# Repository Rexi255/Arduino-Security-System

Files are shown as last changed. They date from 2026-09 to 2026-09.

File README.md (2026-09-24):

<p align="center">
  Projekt GAS: mini security system with keypad, RFID reader and motion sensor
</p>

<p align="center">
  <a href="https://bbz-aifs51.github.io/LF7-Projekt_GAS/"><b>▶ Open the 3D model in your browser</b></a>
  &nbsp;·&nbsp; <a href="MDs/anleitung.md">User manual (German)</a>
  &nbsp;·&nbsp; <a href="Schaltplan/SCHALTPLAN.png">Schematic</a>
  &nbsp;·&nbsp; <a href="Code/alarm_system/alarm_system.ino">Firmware</a>
</p>

A small alarm system on an Arduino Uno R3, built as a school project for
learning field 7 (LF07). You arm and disarm it with a PIN on a 4x4 keypad or
with an RFID card. While it is armed, the motion sensor triggers a 30-second
siren. The OLED only shows icons: a heart when the system is disarmed, a skull
when it is armed, and a flashing skull during an alarm. You add cards right on
the device, no PC needed.

<p align="center">
  State machine: disarmed, exit delay, armed, alarm and admin menu
</p>

## Features

- **Two ways to arm and disarm:** PIN + `#` on the keypad, or a stored RFID card. Both do exactly the same thing.
- **Exit delay:** After arming you have 10 s to leave the room. The buzzer beeps once per second in the meantime.
- **Alarm:** It starts on motion (only while ARMED) or after **3 wrong tries** (wrong PIN or unknown card). The siren runs for 30 s or until the correct PIN or a known card is used.
- **Feedback:** A bright double tone means OK, a rough buzz means an error. The PIN only shows up as `*`, and a wrong entry briefly shows a ✖.
- **Admin menu on the device:** `A` + admin PIN + `#` opens it. There you add cards (just hold them to the reader), or browse and delete the stored ones. Cards live in the internal EEPROM and survive a new upload.
- **RFID reset:** `B` restarts the RC522 in case a clone module hangs.

## Quick controls

| Key | Action |
|---|---|
| `0`–`9` | enter the PIN (shown as `*`) |
| `#` | confirm the entry |
| `*` | clear the entry · in the admin menu: back / exit |
| `A` | while DISARMED: enter the admin PIN → admin menu |
| `B` | while DISARMED: re-initialise the RFID reader |
| Hold a card to the reader | same as the correct PIN (if the card is stored) |

The full end-user manual (in German) is in [MDs/anleitung.md](MDs/anleitung.md),
and as a PDF in [Anleitung/](Anleitung/Mini%20Security%20System%20Manual.pdf).

## Hardware

| Part | Uno connection | Note |
|---|---|---|
| Arduino Uno R3 | – | ATmega328P, 2 KB SRAM |
| 4x4 keypad | rows R1–R4 → D9–D6, columns C1–C4 → D5–D2 | the sketch scans the matrix itself |
| 1.3" OLED 128x64 | SDA → A4, SCL → A5 | **SH1106** controller, I²C address `0x3C` |
| RFID-RC522 | SS → A0, RST → A1, MOSI → D11, MISO → D12, SCK → D13 | **VCC to 3.3 V**, 5 V destroys the module |
| Motion sensor (PIR) | OUT → A2 | active HIGH |
| Passive buzzer | signal → D10 | driven directly from the pin, no transistor |
| 9 V battery | barrel jack | power supply |

All other VCC pins go to 5 V, all GND pins to a common ground. This uses up
every pin on the Uno; only D0/D1 (serial) are left free. The full parts list
is in [Teile.xlsx](Teile.xlsx).

<p align="center">
  Wiring of all parts to the Arduino Uno
</p>

The original Cirkit Designer schematic is in
[Schaltplan/](Schaltplan/SCHALTPLAN.png) (PNG and SVG).

## Getting started

1. Install the **Arduino IDE** and get these libraries from the Library Manager:
   - **Adafruit SH110X** (also install its dependencies *Adafruit GFX* and *Adafruit BusIO*)
   - **MFRC522** (GithubCommunity)
   - **Keypad** (Mark Stanley / Alexander Brevig), only needed for `hardware_test`
   - `Wire`, `SPI` and `EEPROM` already come with the IDE.
2. Set the PIN and admin PIN at the top of [alarm_system.ino](Code/alarm_system/alarm_system.ino) (`PIN_CODE`, `ADMIN_PIN`).
3. Select the **Arduino Uno** board and the right port, then upload.
4. Set the serial monitor to **9600 baud**. On start-up it shows the RC522 version (`0x91`/`0x92` = OK), the number of stored cards and the free SRAM.
5. On the very first start the EEPROM is empty, so the sketch writes the factory list `DEFAULT_UIDS` into it. After that you manage cards only through the admin menu.

If something doesn't work, the test sketches check each part on its own:

| Sketch | Purpose |
|---|---|
| [Code/alarm_system/](Code/alarm_system/alarm_system.ino) | **Main firmware**: state machine, PIN, RFID, admin menu, sounds |
| [Code/hardware_test/](Code/hardware_test/hardware_test.ino) | bring-up test: OLED, keypad, buzzer, motion sensor |
| [Code/display_test/](Code/display_test/display_test.ino) | OLED only (icons + free SRAM) |
| [Code/rfid_test/](Code/rfid_test/rfid_test.ino) | RC522 only (version, UID of every card) |

## 3D model in the browser

**[▶ bbz-aifs51.github.io/LF7-Projekt_GAS](https://bbz-aifs51.github.io/LF7-Projekt_GAS/)**

An interactive 3D model of the build (three.js), laid out after the schematic.
It runs the firmware logic from `alarm_system.ino`, so the states, timings,
sounds and OLED graphics are the same:

- Press keys on the 3D keypad or in the side panel. Your keyboard works too (Enter = `#`, Esc = `*`).
- Click the cards or the key fob: they float over to the RC522 and the SPI lines light up.
- Click the motion sensor to trigger the alarm while ARMED.
- A signal pulse travels along each wire. A key press lights up exactly its row and column wire, and the L LED on D13 flickers during SPI traffic.
- The buzzer plays through WebAudio, and there is a serial monitor and an EEPROM card list.

The model uses demo PINs (`1234` and admin `0000`), not the real ones from the
sketch. To use it offline, just open
[docs/viewer/index.html](docs/viewer/index.html) in your browser.

## Pitfalls we solved

- **The OLED is an SH1106, not an SSD1306.** With the SSD1306 library it stays blank or only shows stripes. The right class is `Adafruit_SH1106G`.
- **SRAM is tight.** The OLED buffer alone takes 1024 of the 2048 bytes. With the Keypad library only ~205 bytes were left, which caused resets and wrong key presses. So the sketch scans the matrix itself, and all strings are kept in flash with `F()`.
- **`SPI.begin()` drives D10 HIGH**, because D10 is the AVR's SS pin. That is exactly where the buzzer sits, so the sketch sets the buzzer pin LOW only *after* `SPI.begin()`.
- **The motion sensor moved to A2**, because D11 is the fixed SPI MOSI pin. A2 works just like any digital pin with `digitalRead()`.
- **Polling the RC522 blocks for ~25 ms** when no card is present. So the sketch only polls the reader every 200 ms, otherwise the keypad gets sluggish and the siren stutters.

## Project structure

| Folder/file | Contents |
|---|---|
| [Code/](Code/) | Arduino sketches, one subfolder per sketch |
| [docs/](docs/) | animated README graphics (SVG) and the 3D viewer (`docs/viewer/`) |
| [MDs/](MDs/) | docs (German): [hardware spec](MDs/aufbau.md), [user manual](MDs/anleitung.md), [development log](MDs/entwicklungsverlauf.md) |
| [Anleitung/](Anleitung/) | user manual as a PDF |
| [Schaltplan/](Schaltplan/) | schematic (PNG/SVG) |
| [Teile.xlsx](Teile.xlsx) | parts list |
| [CLAUDE.md](CLAUDE.md) | project context and hardware facts for development with Claude Code |

The firmware was written together with Claude Code. Every prompt and answer is
logged (in German) in [MDs/entwicklungsverlauf.md](MDs/entwicklungsverlauf.md).

## License

[MIT](LICENSE). The 3D viewer uses [three.js](https://threejs.org/) (MIT,
bundled as `docs/viewer/three.min.js`).

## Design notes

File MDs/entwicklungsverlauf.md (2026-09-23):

# Entwicklungsverlauf — Projekt GAS

Dokumentation der Firmware-Entwicklung mit Claude Code (Claude Opus 5).
Chronologisches Protokoll: Prompts (Jan Mummert) und Antworten (Claude).

- Projekt: LF07 — Mini-Sicherheitssystem / Access Lock (Arduino Uno R3)
- Daten der Sitzungen: 08.09.2026, 22.09.2026, 23.09.2026 (inkl. Gehäuse)
- Grundlagen im Kontext: [../CLAUDE.md](../CLAUDE.md), [aufbau.md](aufbau.md)

---

## 1. Prompt — Auftrag: komplette Firmware

> Use @CLAUDE.md und @MDs/aufbau.md.
>
> Programmiere den kompletten Code für unser Projekt.
>
> Was wir wollen: Ein mini Sicherheitssystem/Doorlock/Access Lock.
> Der Buzzer soll einen Alarmton abspielen, wenn der Motion sensor ausgelöst
> ist. Man soll die Alarmanlage mit einem Pin (später auch mit rfid, aber das
> ist nur eine Idee für ein feature wenn alles läuft) entschärfen können und
> auch wieder mit dem Pin scharf schalten können. Das Display soll im scharfen
> zustand einen Totenkopf anzeigen, wenn man Pin eingibt sollen anstelle des
> Pins nur Sternchen "*" angezeigt werden, die Eingabe des Pins soll man mit
> "#" bestätigen können. Bei richtigem Pin soll ein heller angenehmer
> Bestätigungston kommen, Bei Falsch eingabe ein Rauer längerer Ton (3sek).
> Bei 3 facher fehleingabe soll der Alarm der Anlage ertönen.
> Im Entsperrten zustand soll das Display ein Herz anzeigen.
>
> Im Unscharfen zustand soll der Motion Sensor natürlich keinen Alarm auslösen,
> nur wenn die Anlage scharf ist.
> Der Alarm soll extrem laut und schrill sein, er soll 30 sekunden dauern.

### Antwort

Fertig: [../Code/alarm_system/alarm_system.ino](../Code/alarm_system/alarm_system.ino)
— die komplette Firmware, Pins genau wie in aufbau.md/CLAUDE.md
(SDA=A4, SCL=A5, SH1106 @0x3C).

**Zustände**

- `UNSCHARF` — Herz auf dem Display, Bewegungssensor wird ignoriert.
- `SCHARF IN xs` — Ausgangsverzögerung (10 s, Piep pro Sekunde), damit du nach
  dem Scharfschalten den Raum verlassen kannst, ohne dich selbst auszulösen.
  Das hattest du nicht verlangt, ohne das löst die Anlage aber sofort beim
  eigenen Zurücktreten aus — Wert steht als `EXIT_DELAY_MS` oben, auf 0 setzen
  wenn du es nicht willst.
- `SCHARF` — Totenkopf, Bewegung (steigende Flanke auf D11) löst Alarm aus.
- `ALARM` — blinkendes „ALARM!!", Totenkopf, Restsekunden; Sirene 30 s, danach
  automatisch wieder scharf.

**Bedienung am Keypad**

- `0-9` PIN eingeben, auf dem Display nur `*` (Größe 2, mittig)
- `#` bestätigen → richtiger PIN schaltet scharf/unscharf und beendet den
  laufenden Alarm sofort
- `*` Eingabe löschen; halb getippte PIN verfällt nach 10 s von selbst
- PIN steht oben als `const char PIN_CODE[] = "1234";`

**Töne** (nicht-blockierend, Keypad bleibt währenddessen bedienbar)

- Richtig: zwei helle kurze Noten (G6 → C7)
- Falsch: rauer tiefer Brummton, 3 s (schnelles Wechseln 95/135 Hz)
- 3× falsch: voller Alarm — das gilt in jedem Zustand, also auch im unscharfen
  (Sabotage). Wenn du das nur im scharfen Zustand willst, sag Bescheid.
- Alarm: Sirenen-Sweep 2500↔3700 Hz, bewusst im lautesten Bereich des Piezos,
  30 s

**Nicht verifiziert:** Ich konnte den Sketch hier nicht kompilieren —
arduino-cli ist auf dem Rechner nicht vorhanden. Bitte einmal in der Arduino
IDE bauen und hochladen; die Bibliotheken sind dieselben wie beim
`hardware_test`.

---

## 2. Prompt — Display zeigt Pixelmüll

> Das Display bugt ein wenig, es zeigt weder das herz, noch einen totenkopf
> oder ähnliches an. Auch der Code etc. wird nicht richtig angezeigt. man kann
> die sekundne timer erahnen, aber das wars. Das display hat diese specs:
>
> - Module dimensions: 36 mm x 34 mm x 3 mm
> - Dot Matrix: 128 x 64
> - Pixel size: 0.21 mm × 0.21 mm
> - Pixel pitch: 0.23 mm × 0.23 mm
> - Display Mode: Passive Matrix
> - Duty: 1/64 Duty
> - Display Color: Blue
> - Interface: I2C
> - Power consumption: Less then 11mA
> - Size: 1.3 inch

### Antwort

Das klingt nach einem Anzeige-/Speicherproblem, nicht nach falscher Geometrie —
1,3" 128x64 I2C ist praktisch immer der SH1106, und der `hardware_test` lief ja.
Ich mache zwei Dinge: einen isolierten Display-Test zum Eingrenzen und die
Hauptfirmware deutlich RAM-sparsamer.

Der wahrscheinlichste Verdacht: Der Uno hat 2 KB SRAM, der Framebuffer belegt
davon allein 1 KB. `snprintf("%lu")` und die Text-Literale im RAM treiben den
Stack so weit hoch, dass er in den Framebuffer läuft — das ergibt genau so ein
Bild, in dem man Reste (die Sekundenzahlen) noch erahnen kann.

Zwei Sachen, bitte in dieser Reihenfolge testen:

**1. [../Code/display_test/display_test.ino](../Code/display_test/display_test.ino)
hochladen** (nur das Display, sonst nichts). Er zeigt im 2-Sekunden-Takt:
Rahmen+Text → Herz → Totenkopf → `****`, und schreibt vor jedem Bild den freien
SRAM in den Seriellen Monitor.

- Sehen die vier Bilder korrekt aus → das Display kann alles, das Problem ist
  der Speicher im Hauptsketch (siehe Punkt 2).
- Sind sie auch hier kaputt → es liegt am Display selbst; dann sag mir bitte,
  *wie* kaputt (verschoben, gestreift, Rauschen) und was der Rahmen macht. Dann
  ist der Controller vermutlich doch kein SH1106, und ich baue auf SSD1306 bzw.
  auf einen Spaltenversatz um.

**2. [../Code/alarm_system/alarm_system.ino](../Code/alarm_system/alarm_system.ino)
ist überarbeitet.** Was ich geändert habe und warum:

Der Uno hat 2048 Byte SRAM, davon frisst der OLED-Framebuffer allein 1024. Dazu
Keypad-Library, Wire- und Serial-Puffer — es bleiben nur ein paar hundert Byte
Stack. `snprintf("%lu")` braucht davon über 100 Byte auf einen Schlag, und die
Text-Literale `"UNSCHARF"` usw. lagen zusätzlich im RAM. Wenn der Stack in den
Framebuffer läuft, sieht man genau das, was du beschreibst: Pixelmüll, in dem
man Reste (deine Sekundenzahlen) noch erahnen kann.

Deshalb jetzt:

- kein `snprintf` mehr — der Countdown wird direkt mit `display.print()`
  ausgegeben
- alle Display-Texte über `F(...)` im Flash statt im RAM
- keine temporären `char`-Puffer mehr (die Sternchen werden in einer Schleife
  gedruckt)
- `setup()` gibt `free SRAM:` über Serial aus — der Wert sollte deutlich über
  250 liegen

Der Funktionsumfang ist unverändert. Die Icons habe ich zusätzlich leicht
anders positioniert, damit sich Totenkopf und die Sternchen-Zeile nicht mehr
überlappen.

Melde mir die vier Testbilder und den SRAM-Wert, dann weiß ich, in welche
Richtung es geht. Kompilieren kann ich hier weiterhin nicht — auf dem Rechner
ist keine arduino-cli installiert.

---

## 3. Prompt — Dokumentation

> Packe alle Prompts von mir und deine antworten in einer .md datei. wir
> brauchen das als dokumentation

### Antwort

Dieses Dokument. Es wird bei weiteren Änderungen fortgeschrieben.

---

## 4. Prompt — Resets beim Scharfschalten, Text soll weg

> Funktioniert soweit.
>
> 1. Sehr oft, nachdem es einmal armed und disarmed wurde kann man es nicht
>    erneut armen. Es zeigt im serial pin wrong an obwohl dieser richtig
>    eingegeben wurde:
>
>    ```
>    free SRAM: 205
>    [PIN] wrong 1
>    [PIN] correct
>    [STATE] arming - exit de=== Alarm system ready (disarmed) ===
>    PIN + '#' arms / disarms, '*' clears the entry.
>    free SRAM: 205
>    [PIN] wrong 1
>    ```
>
> 2. Entferne den Text bei den Symbolen, es soll nur Totenkopf oder Herz ohne
>    Text angezeigt werden. Der Sekundentimer ist etwas zu groß, die hälfte der
>    Zahl verschwindet weil es über den display rand hinaus geht.

### Antwort

**Zu 1 — der Arduino startet neu.** Im Log bricht die Zeile
`[STATE] arming - exit de` mitten im Wort ab und danach kommt wieder der
Startbanner `=== Alarm system ready ===`. Das ist ein Reset, kein Logikfehler.
Ursache ist der freie SRAM: **205 Byte**. Davon muss der komplette Stack leben,
inklusive der Interrupts, die `tone()` erzeugt (bei 3700 Hz sind das 7400
Interrupts pro Sekunde). Wenn so ein Interrupt zuschlägt, während der
Display-Code tief im Stack steht, läuft der Stack in den Framebuffer und in die
globalen Variablen — mal gibt es einen Reset, mal wird nur `entry[]` verfälscht,
und dann meldet der Sketch „PIN wrong" obwohl richtig getippt wurde. Das erklärt
auch, warum es erst *nach* dem ersten Scharfschalten auftritt: vorher hat noch
kein Ton gespielt.

Der größte Speicherfresser nach dem Framebuffer war die **Keypad-Library**: sie
hält 10 `Key`-Objekte, eine Bitmap und die Keymap im RAM, zusammen rund 120 Byte.
Die habe ich rausgeworfen und den 4x4-Scan selbst geschrieben — für eine Matrix
sind das ungefähr 30 Zeilen:

- Zeilen auf `INPUT_PULLUP`, Spalten hochohmig (`INPUT`)
- pro Scan eine Spalte auf `OUTPUT`/LOW ziehen und die vier Zeilen lesen
- Keymap liegt jetzt im Flash (`PROGMEM` + `pgm_read_byte`)
- eigenes Entprellen (20 ms), eine Taste wird genau einmal beim Drücken gemeldet

Damit sollten rund **320–330 Byte** frei sein. Der Wert steht wie vorher beim
Start im Seriellen Monitor — bitte einmal nachsehen und mir sagen, was dasteht.
Zusätzlich gibt der Sketch jetzt jede erkannte Taste (`[KEY] 4`) und die
komplette Eingabe vor der Prüfung (`[PIN] entered: 1234`) aus. Falls doch noch
etwas verschluckt wird, sieht man es damit sofort.

Die Keypad-Library wird für diesen Sketch nicht mehr gebraucht; der
`hardware_test` benutzt sie weiterhin, also bitte installiert lassen.

**Zu 2 — Anzeige.** Aller Statustext ist raus, es gibt nur noch die Icons:

- UNSCHARF: Herz, mittig
- SCHARF: Totenkopf, mittig
- Ausgangsverzögerung: Totenkopf + Countdown darunter
- ALARM: Totenkopf, der im 250-ms-Takt das ganze Display invertiert, darunter
  die Restsekunden (auch das „ALARM!!" ist weg — sagt Bescheid, wenn ihr das
  Wort zurückhaben wollt)

Der abgeschnittene Countdown war ein vertikales Problem, kein horizontales: die
Zahl stand in Größe 2 auf y = 52, das sind 16 Pixel Höhe bis y = 68 — das
Display hört bei 63 auf, also fehlte die untere Hälfte. Jetzt sitzt sie auf
y = 46 bzw. y = 47 und passt.

Während der PIN-Eingabe zeigt das Display nur noch die Sternchen, groß und
mittig. Grund: Totenkopf und Sternchen brauchen zusammen mehr als 64 Pixel Höhe,
sie hätten sich sonst überlappt.

---

## 5. Prompt — Kollisionserkennung und Rechtevergabe bei RFID

> Erkläre uns was unsere Lehrerin mit Kollisionserkennung und Rechtevergabe im
> bezug auf RFID meint

### Antwort

Zwei verschiedene Ebenen, die beim RFID-Teil oft durcheinander geworfen werden:

**Kollisionserkennung — Protokoll-Ebene (ISO 14443A)**

Liegen mehrere Karten gleichzeitig im Feld des RC522, würden bei einer
einfachen Anfrage alle gleichzeitig antworten — das ist eine *Kollision*. Der
ISO-14443A-Standard löst das über ein Anti-Kollisions-Verfahren: Der Reader
fragt die UID Bit für Bit in Kaskaden ab, bis genau eine Karte eindeutig
identifiziert ist. Bei uns läuft das komplett innerhalb der MFRC522-Library ab,
über die Aufrufe

```cpp
mfrc522.PICC_IsNewCardPresent()
mfrc522.PICC_ReadCardSerial()
```

in [readRfidUid()](../Code/alarm_system/alarm_system.ino#L326). Der Aufruf
[mfrc522.PICC_HaltA()](../Code/alarm_system/alarm_system.ino#L339) danach
schickt die gelesene Karte in den HALT-Zustand, damit sie nicht bei jedem
Poll-Zyklus erneut "kollidiert" bzw. neu gelesen wird, solange sie liegen
bleibt.

**Rechtevergabe — Anwendungsebene (Access Control)**

Unsere jetzige Logik ist rein binär: Eine UID steht in
[ALLOWED_UIDS](../Code/alarm_system/alarm_system.ino#L77) oder nicht, geprüft
in [isAllowedUid()](../Code/alarm_system/alarm_system.ino#L350) — jede erlaubte
Karte darf alles, was das System kann (scharf/unscharf schalten). Mit
"Rechtevergabe" ist vermutlich eine feinere Unterscheidung gemeint, z. B.:

- unterschiedliche Rollen pro Karte (manche dürfen nur entschärfen, andere
  auch neue Karten anlernen)
- Karten zur Laufzeit hinzufügen/entziehen können, statt sie fest im Code
  (`PROGMEM`) zu hinterlegen
- Protokollierung, wer wann welche Karte benutzt hat, statt nur ja/nein

Für den Umfang dieses Schulprojekts bleibt es bei der einfachen
Allow-List-Prüfung — das oben ist als konzeptionelle Erklärung für die
Dokumentation/Präsentation gedacht, nicht als Implementierungsauftrag.

---

## 6. Prompt — Rechtevergabe umsetzen: UIDs außerhalb des Codes verwalten

> Thema Rechtevergabe. Man soll die uids außerhalb des Codes verändern, bzw.
> sperren oder hinzufügen können. Wie könnte man das lösen. Plane erst

### Antwort

Aufbauend auf Eintrag 5 (dort nur konzeptionell besprochen, bewusst nicht
umgesetzt) jetzt tatsächlich implementiert, nach Rückfrage zur Bedienung:

- Admin-Interface komplett über Keypad + OLED (keine Serial-Kommandos, kein
  PC nötig)
- Löschen entfernt eine UID sofort, keine separate Sperrliste

**Speicherung:** UIDs liegen jetzt im internen EEPROM des Uno statt fest im
Code (`DEFAULT_UIDS` bleibt nur als Werksvorgabe fürs allererste Booten).
Kein Zusatzmodul (z. B. SD-Karte) nötig und laut CLAUDE.md auch gar nicht
möglich — kein Pin mehr frei. EEPROM übersteht ein Neu-Hochladen des Sketches.

**Bedienung:** Taste `A` im UNSCHARF-Zustand + eine eigene `ADMIN_PIN` + `#`
öffnet einen neuen Zustand `STATE_ADMIN` mit kleinem Text-Menü auf dem OLED
(bisher zeigte das Display nur Icons — hier bewusste Ausnahme, siehe
[Code/alarm_system/alarm_system.ino](../Code/alarm_system/alarm_system.ino#L885)):

- `1` Karte anlernen — auflegen genügt, kein manuelles Abtippen der Hex-UID
  mehr (das war vorher nötig, siehe `rfid_test.ino`)
- `2` Liste durchblättern (`#`), Karte löschen (`D`)
- `*` Menü verlassen; nach `ADMIN_IDLE_TIMEOUT_MS` (20 s) auch automatisch

Eine falsche Admin-PIN läuft über denselben `accessDenied()`-Pfad wie eine
falsche normale PIN — zählt also zu den 3 Fehlversuchen und löst genauso
Alarm aus (Bruteforce-Schutz für beide PINs einheitlich).

`MAX_STORED_UIDS` bewusst klein (8) gewählt wegen des knappen SRAMs (siehe
Memory Note in CLAUDE.md) — mehr Platz wäre im EEPROM (1024 Byte) locker da,
das RAM ist der eigentliche Engpass.

Vor der Änderung wurde eine Kopie der alten Version unter
`Code/alarm_system/alarm_system.ino.bak` gesichert.

**Offener Punkt:** Wie in Eintrag 4 — kein `arduino-cli` auf diesem Rechner,
der Sketch wurde nicht kompiliert. Vor dem Hochladen in der Arduino IDE
verifizieren und danach die Punkte aus dem Plan durchgehen (u. a.: passt
`free SRAM` noch, wandert die bestehende `DEFAULT_UIDS`-Karte korrekt ins
EEPROM, funktioniert Anlernen/Löschen, löst 3x falsche Admin-PIN den Alarm
aus, übersteht eine neue Karte ein erneutes Hochladen).

---

## 7. Prompt — RFID-Reset (22.09.2026)

> Unsere Lehrerin hat bei einer anderen Gruppe angemerkt, dass sie keinen
> RFID-Reset haben, da sich das RFID-Modul wohl öfters mal aufhängen kann.
> Wie könnten wir sowas bei uns einbauen, bzw. ist das überhaupt nötig? Falls
> ja könnte man da ja auch z. B. den Buchstaben B beim Tastenfeld setzen.

### Antwort

Ja, sinnvoll: RC522-Klone können SPI-seitig hängen bleiben (`VersionReg`
antwortet dann wieder mit `0x00`/`0xFF` statt `0x91`/`0x92`), erkennbar an
Karten, die plötzlich nicht mehr gelesen werden — sonst hilft nur ein
kompletter Neustart des Uno. `RST_PIN` (A1) ist bei uns ohnehin schon
verdrahtet, ein Reset zur Laufzeit ist also reine Software.

Rückfrage, ob nur manuell per Taste, zusätzlich automatisch im Hintergrund,
oder gar nicht — Antwort: nur manuell. Umgesetzt in
[../Code/alarm_system/alarm_system.ino](../Code/alarm_system/alarm_system.ino):

- Neue Funktion `resetRfid()` (`PCD_Reset()` + `PCD_Init()`, danach
  `VersionReg` neu geprüft und `rfidOk` aktualisiert; OK-/Fehlerton als
  Feedback)
- Taste `B` im Zustand UNSCHARF ruft `resetRfid()` auf — bisher unbelegt,
  analog zur `A`-Abfrage fürs Admin-Menü (nur bei `entryLen == 0`)
- Kopf-Kommentar im Sketch und [../CLAUDE.md](../CLAUDE.md) (Abschnitt
  „Sketches") entsprechend ergänzt

**Offener Punkt:** wie in den vorherigen Einträgen nicht kompiliert (kein
`arduino-cli` auf dem Rechner) — vor dem nächsten Hochladen in der Arduino
IDE prüfen, außerdem am echten Aufbau testen, ob `B` den Reader nach einem
gezielten Verbindungsabbruch (z. B. RST kurz trennen) tatsächlich wiederbelebt.

---

## 8. Prompt — 3D-Animationen und neue README (23.09.2026)

> Schaue dir dieses Github Repo von einem freund an:
> https://github.com/BBZ-AIFS51/LF7-MiniCasino
>
> Ich möchte das in dem Github repo von diesem Projekt auch so coole 3d
> animationen wie bei denen sind. Verwende dafür unsere dokumentation. Dabei
> kannst du Auch gleich die README unseres Projekts einmal komplett überarbeiten

### Antwort

Das MiniCasino-Repo nutzt zwei Dinge: animierte SVG-Grafiken direkt in der
README (CSS-Animationen, laufen auch auf GitHub) und einen three.js-3D-Viewer,
der über GitHub Pages läuft. Beides gibt es jetzt auch bei uns, aufgebaut aus
CLAUDE.md, aufbau.md, anleitung.md, dem Schaltplan und der Firmware:

- [../docs/banner.svg](../docs/banner.svg): isometrisches Gerät, das in 10 s
  einmal UNSCHARF → PIN → SCHARF → ALARM durchläuft. Herz und Totenkopf mit
  denselben Koordinaten wie `drawHeart()`/`drawSkull()`, die Alarm-Anzeige
  invertiert wie im Sketch, dazu eine schwebende RFID-Karte.
- [../docs/how-it-works.svg](../docs/how-it-works.svg): Zustandsautomat mit
  laufenden Pfeilen, dem jeweils aktiven Zustand und Fortschrittsbalken für
  10 s / 30 s.
- [../docs/wiring.svg](../docs/wiring.svg): Verdrahtung am Uno, Signalpulse
  zeigen die Richtung, Hinweis auf 3,3 V beim RC522.
- [../docs/viewer/index.html](../docs/viewer/index.html): 3D-Modell des
  Steckbrett-Aufbaus nach dem Schaltplan. Die Firmware-Logik ist 1:1 nach
  JavaScript übertragen (Zustände, Zeiten, Töne über WebAudio, OLED als
  128x64-Framebuffer mit denselben GFX-Aufrufen, Admin-Menü, EEPROM im
  localStorage). Tasten, Karten und PIR sind anklickbar, Signalpulse laufen
  über die Kabel. Im Modell gelten Demo-PINs (`1234`/`0000`), nicht die echten.
- [../.github/workflows/pages.yml](../.github/workflows/pages.yml): veröffentlicht
  den Viewer auf GitHub Pages.
- [../README.md](../README.md) komplett neu geschrieben.

Getestet: SVGs und Viewer im Edge (headless) gerendert, die Viewer-Logik mit
einem Skript durchgespielt (PIN, Ausgangszeit, Bewegung → Alarm,
3 Fehlversuche, Admin-PIN, Karte anlernen/löschen, 7-Byte-UID abgelehnt,
Eingabe-Timeout). Alle Prüfungen sind bestanden.

**Offener Punkt:** GitHub Pages muss einmalig unter *Settings → Pages →
Source: GitHub Actions* aktiviert werden. Der Fehlerton dauert laut Sketch
`ERROR_TONE_MS = 2000` (2 s), Kommentare und CLAUDE.md sagen noch 3 s.

---

## 9. Prompt — README, Grafiken und Viewer auf Englisch (23.09.2026)

> Ändere die Readme auf englisch
>
> Ja stelle auch den viewer auf englisch um und pushe alles dann

### Antwort

[../README.md](../README.md) ins Englische übersetzt (Inhalt unverändert,
deutsche Doku-Links mit „(German)“ markiert). Alle Texte in den drei SVGs unter
[../docs/](../docs/) und die komplette Oberfläche des 3D-Viewers (Seitenleiste,
Tooltips, Beschriftungen, Kartenaufdrucke) sind jetzt englisch. Die OLED- und
Serial-Texte waren schon englisch, weil sie aus dem Sketch stammen. Grafik und
Viewer danach erneut gerendert und geprüft.

---

## 10. Prompt — Gehäuse für den 3D-Druck (23.09.2026)

> Plane und entwerfe ein Gehäuse. Das Gehäuse soll 3D gedruckt werden. Ich habe
> 0 Erfahrung was sowas angeht.
>
> Wichtig ist, dass der Bewegungssensor auf der anderen seite sein muss, also
> quasi ist alles vorne an einer tür/Türrahmen und auch der anderen seite ist
> der bewegungssensor, sodass er halt erst was erkennt wenn man den raum
> betritt und nicht auslöst wenn man nur an den türrahmen rantritt um es zu
> entsperren.
>
> Plane erst das Gehäuse, dann entwerfe es

### Antwort

Zwei Gehäuse statt einem: **Bedienteil** außen neben der Tür (Uno, Keypad,
OLED, RC522, Buzzer, 90 × 176 × 45 mm) und **Sensorteil** innen im Raum
(HC-SR501, 52 × 44 × 35 mm), verbunden über ein 3-adriges Kabel. Der PIR sieht
nur in direkter Sichtlinie, die Wand verdeckt also die Person am Bedienteil.

- [gehaeuse.md](gehaeuse.md): Planung (Konzept, Aufteilung, Montageort) und
  Einsteiger-Anleitung (Nachmessen, Slicen, Einkaufsliste, Zusammenbau,
  Anpassen in OpenSCAD).
- [../Gehaeuse/gehaeuse.scad](../Gehaeuse/gehaeuse.scad): parametrisches
  OpenSCAD-Modell, alle Maße oben als Variablen.
- [../Gehaeuse/stl/](../Gehaeuse/stl/): vier fertige Druckteile, bereits in
  Druckrichtung, ohne Stützstrukturen druckbar.

Mit OpenSCAD 2021.01 gerendert: alle vier STLs sind geschlossen („Simple:
yes“). Die Frontansicht wurde auf nicht gespiegelte Gravuren geprüft.
**Offener Punkt:** Die Modulmaße stammen aus Datenblättern und sind nicht am
echten Aufbau gemessen. Außerdem ist noch nichts gedruckt.

---

## Anhang — Stand der Dateien

| Datei | Zweck |
|---|---|
| [../Code/hardware_test/hardware_test.ino](../Code/hardware_test/hardware_test.ino) | Bring-up-Test aller Bauteile (vor dieser Sitzung entstanden) |
| [../Code/alarm_system/alarm_system.ino](../Code/alarm_system/alarm_system.ino) | Hauptfirmware: Zustandsautomat, PIN, Icons, Töne |
| [../Code/display_test/display_test.ino](../Code/display_test/display_test.ino) | Isolierter OLED-Test + SRAM-Anzeige zur Fehlersuche |
| [../CLAUDE.md](../CLAUDE.md) | Projektvorgaben, Pinbelegung, Hardware-Fakten, SRAM-Hinweis |

**Offener Punkt:** Die Reset-Diagnose (zu wenig freier SRAM) gilt erst als
bestätigt, wenn der neue `free SRAM:`-Wert im Seriellen Monitor deutlich über
300 liegt und die Resets ausbleiben. Kein Sketch
dieser Sitzung wurde kompiliert, da auf dem Rechner keine arduino-cli vorhanden
ist.

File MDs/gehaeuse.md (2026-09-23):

# Gehäuse — Planung und Entwurf

3D-druckbares Gehäuse für das Mini-Sicherheitssystem. Geschrieben für
Einsteiger: Es wird nichts an Vorwissen über 3D-Druck vorausgesetzt.

- Modell (zum Anpassen): [../Gehaeuse/gehaeuse.scad](../Gehaeuse/gehaeuse.scad)
- Fertige Druckdateien: [../Gehaeuse/stl/](../Gehaeuse/stl/)
- Bilder: [../Gehaeuse/bilder/](../Gehaeuse/bilder/)

---

## Teil 1 — Planung

### Anforderungen

1. Keypad, Display, RFID-Leser und Buzzer sitzen **außen** an der Tür bzw.
   neben dem Türrahmen — dort wird ent- und verriegelt.
2. Der Bewegungssensor sitzt **auf der anderen Seite, im Raum**. Er soll erst
   auslösen, wenn jemand den Raum betritt, nicht schon, wenn man zum
   Entsperren vor der Tür steht.
3. Druckbar ohne Erfahrung: keine Stützstrukturen, passt auf kleine Drucker,
   Befestigung mit einfachen Schrauben und Heißkleber.
4. Keine Änderung an Firmware oder Verdrahtung nötig.

### Konzept: zwei Gehäuse, ein Kabel

Montage von oben

- **Bedienteil** (außen): Keypad, OLED, RC522, Buzzer und der Arduino Uno.
- **Sensorteil** (innen): nur der HC-SR501.
- Verbunden über ein **3-adriges Kabel** (5V, GND, OUT → A2). Der Bewegungs-
  sensor braucht nur diese drei Leitungen, ein langes Kabel ist für das
  digitale Signal kein Problem.

**Warum das funktioniert:** Ein PIR-Sensor „sieht“ Wärmestrahlung nur in
direkter Sichtlinie. Wände, Türen und sogar normales Glas blockieren sie.
Der Sensor zeigt in den Raum, die Wand steht zwischen ihm und der Person am
Bedienteil — die kann er also gar nicht erfassen. Erst wer die Tür öffnet
und eintritt, läuft in den Erfassungsbereich.

### Bedienteil (außen)

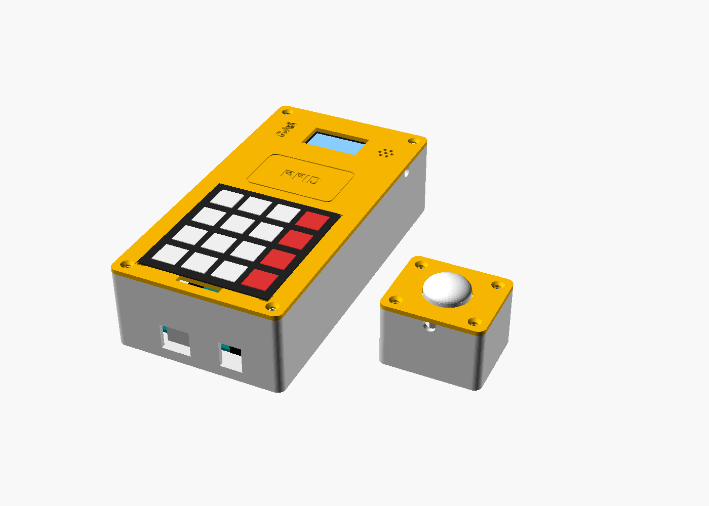
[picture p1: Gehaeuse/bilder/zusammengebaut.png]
Bedienteil zusammengebaut


Größe: **90 × 176 × 45 mm** (B × H × T). Zwei Druckteile: Rückteil (Wanne) und
Frontplatte.

| Bereich | Bauteil | Befestigung |
|---|---|---|
| oben | OLED hinter einem Fenster (32 × 18 mm) | seitliche Führungen, nach oben/unten schiebbar bis das Bild mittig sitzt, dann Heißkleber |
| oben rechts | Buzzer hinter 7 Schalllöchern | Ring als Halter + Heißkleber |
| Mitte | RC522 hinter der Frontplatte, Feld „RFID“ eingraviert | vier Eckführungen + Heißkleber. Die Karte liest durch 2,4 mm Kunststoff problemlos |
| unten | Folien-Keypad **außen aufgeklebt** (Klebefolie auf der Rückseite) | Eckmarken zeigen die Position, das Flachkabel geht durch einen Schlitz direkt darunter |
| hinten | Arduino Uno auf 4 Abstandshaltern, USB-/Strombuchse zeigt nach unten | 4 Schrauben |
| hinten, über dem Uno | Platz für ein Mini-Breadboard (5V-/GND-Verteilung) | Klebefolie |

Das RFID-Feld liegt bewusst **nicht** hinter dem Keypad: Die Folientastatur hat
Leiterbahnen aus Metall, die das Funkfeld stören würden.

Öffnungen im Rückteil:

- unten: Aussparungen für **USB-B** und **Hohlstecker** (Stromversorgung)
- Rückwand: **Kabelloch Ø 8 mm** (Kabel direkt durch die Wand zum Sensor)
- links und rechts: je eine **Kabelkerbe** am Rand (Kabel außen auf der Wand
  verlegt — nimm die Seite, die zur Tür zeigt)
- Rückwand: 2 **Löcher für die Wandmontage** (Schraubenkopf versenkt, die
  Rückseite bleibt flach — geht also auch mit Klebestreifen)

### Sensorteil (innen)

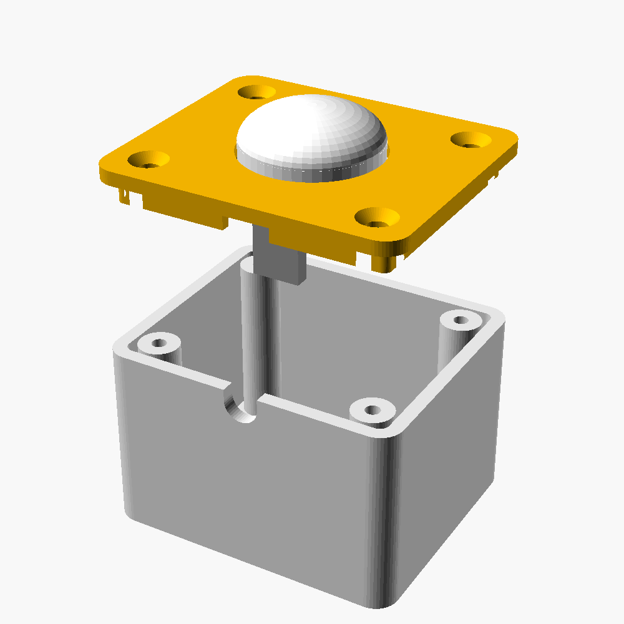
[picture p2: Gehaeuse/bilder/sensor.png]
Sensorteil


Größe: **52 × 44 × 35 mm**. Die Linse (weiße Kuppel) schaut vorne heraus, die
Platine hängt an zwei Zapfen an der Frontplatte. Nach dem Abnehmen der Front
kommt man an die beiden Drehregler (Empfindlichkeit, Haltezeit). Kabel raus
durch Loch in der Rückwand oder Kerbe unten.

### Montageort

- **Bedienteil:** außen neben dem Türrahmen auf der Schlossseite, Oberkante
  etwa auf **1,40 m** — dann ist das Display gut lesbar.
- **Sensorteil:** innen auf **derselben Wand** neben der Tür, etwa
  **1,5–2 m hoch**, Kuppel zeigt in den Raum. Nicht auf Heizkörper, Fenster
  mit direkter Sonne oder Lüftungen richten (Fehlalarme durch Wärme).
- **Kabel** nie durch den Türspalt auf der Schlossseite führen (wird
  eingeklemmt). Entweder ein kleines Loch durch die Wand (Ø 6–8 mm) oder
  mit Kabelclips außen um den Türrahmen herum.
- **Für die Präsentation:** Ein Brett oder eine stabile Pappe spielt die Wand:
  Bedienteil vorne, Sensorteil hinten, Kabel durch ein Loch im Brett.

### Designentscheidungen für den 3D-Druck

- **Jedes Teil liegt mit einer großen, flachen Seite auf dem Druckbett.** Die
  Frontplatte wird mit der Sichtseite nach unten gedruckt → glatte Front,
  Gravuren gelingen sauber. Keine Stützstrukturen nötig.
- Die Frontplatte hat einen umlaufenden **Rand (Lippe)**, der in das Rückteil
  greift — so rutscht nichts und sie sitzt von selbst mittig.
- **Schrauben direkt in den Kunststoff:** Die Löcher haben 2,5 mm, eine 3-mm-
  Schraube schneidet sich ihr Gewinde selbst. Keine Gewindeeinsätze nötig.
- Wandstärke 2,4 mm = 6 Druckbahnen bei der üblichen 0,4-mm-Düse. Stabil,
  aber nicht übertrieben.
- **Positionier-Führungen statt exakter Halter:** Die Maße der Module kommen
  aus Datenblättern, und Klone weichen gern ein paar Zehntel ab. Führungen +
  Heißkleber verzeihen das.
- Größtes Teil 90 × 176 mm → passt auch auf kleine Drucker (180 × 180 mm Bett).

---

## Teil 2 — Entwurf

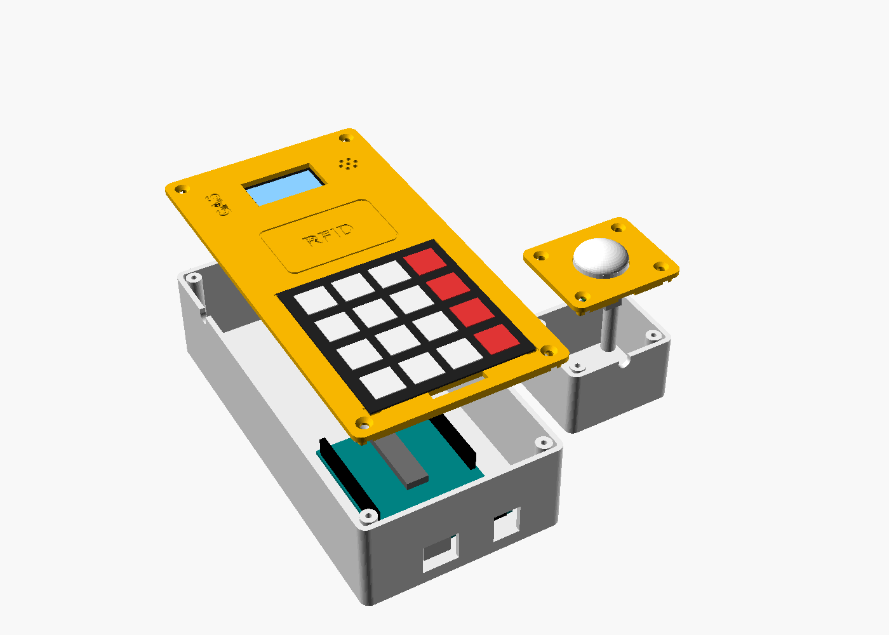
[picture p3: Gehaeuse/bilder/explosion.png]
Explosionsansicht


| Datei | Teil | Druckzeit (ca.) | Material (ca.) |
|---|---|---|---|
| [control_back.stl](../Gehaeuse/stl/control_back.stl) | Bedienteil, Rückteil | 6–8 h | 100 g |
| [control_front.stl](../Gehaeuse/stl/control_front.stl) | Bedienteil, Frontplatte | 2–3 h | 45 g |
| [sensor_back.stl](../Gehaeuse/stl/sensor_back.stl) | Sensorteil, Rückteil | 1,5–2 h | 25 g |
| [sensor_front.stl](../Gehaeuse/stl/sensor_front.stl) | Sensorteil, Frontplatte | 20–30 min | 6 g |

Zusammen rund 180 g PLA, also ca. 4–5 € Material. Die Zeiten hängen stark vom
Drucker ab — der Slicer zeigt den genauen Wert an.

| Frontplatte von vorne | Frontplatte von innen | Rückteil |
|---|---|---|
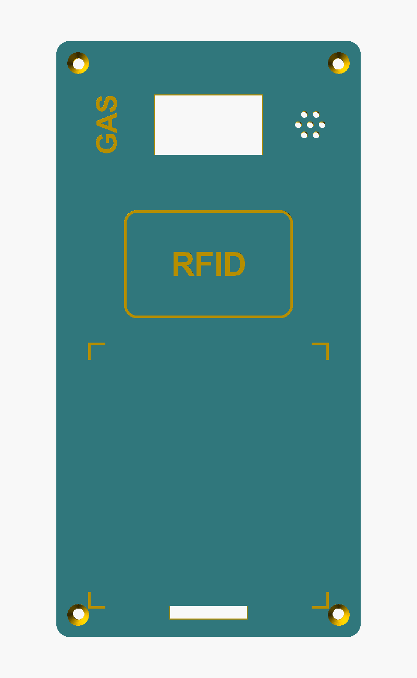
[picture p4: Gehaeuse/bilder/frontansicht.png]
Front
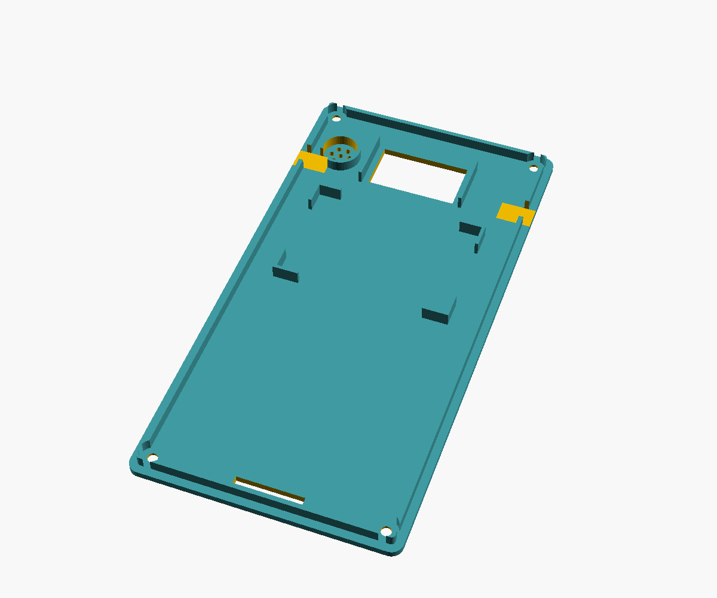
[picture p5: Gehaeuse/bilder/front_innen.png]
Innen
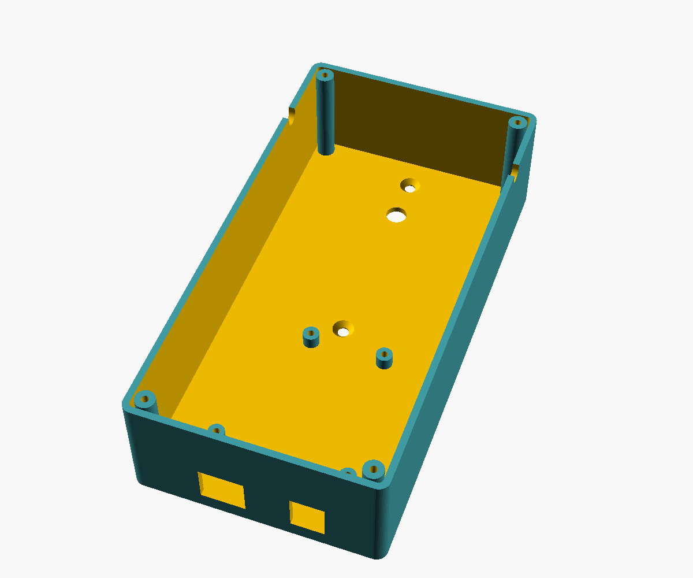
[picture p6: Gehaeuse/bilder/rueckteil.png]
Rückteil
|  |  |  |

### Schritt 1 — Vor dem Drucken nachmessen

Die Maße stammen aus Datenblättern, nicht vom echten Aufbau. Einmal mit Lineal
oder Messschieber prüfen. Weicht etwas um **mehr als 1 mm** ab, den Wert in der
`.scad`-Datei ändern (siehe Schritt 6):

| Was messen | Variable | Annahme |
|---|---|---|
| Folien-Keypad Breite × Höhe (ohne Flachkabel) | `keypad_w`, `keypad_h` | 69,5 × 77 mm |
| Stecker am Ende des Keypad-Flachkabels (muss durch den Schlitz) | `ribbon_slot_w`, `ribbon_slot_h` | Schlitz 23 × 4 mm |
| RC522-Platine | `rfid_w`, `rfid_h` | 60 × 40 mm |
| OLED-Platine | `oled_w`, `oled_h` | 36 × 34 mm |
| Durchmesser des Buzzers (schwarzer Zylinder) | `buzzer_d` | 12 mm |
| HC-SR501: Linse Ø und Abstand der 2 Befestigungslöcher | `pir_dome_d`, `pir_hole_dist` | 23 mm / 28 mm |

Außerdem kurz nachsehen:

- **OLED:** Zeigen die 4 Pins nach hinten (weg vom Display)? Sonst stoßen sie
  an die Frontplatte.
- **RC522:** Dem Modul liegen meist eine gerade und eine **gewinkelte
  Stiftleiste** bei. Die gewinkelte spart Platz nach hinten. Ist schon eine
  gerade eingelötet, geht es auch so, die Kabel müssen dann etwas gebogen werden.

**Tipp:** Zuerst nur die kleine Sensor-Frontplatte drucken (≈ 30 min) und
prüfen, ob die Linse durchpasst und die Löcher sitzen. So sieht man schnell,
ob der Drucker maßhaltig druckt, bevor die großen Teile dran sind.

### Schritt 2 — Wo drucken?

- Schul-/Ausbildungsbetrieb-Drucker, Makerspace oder FabLab in der Nähe,
  manche Stadtbibliotheken
- Bekannte mit Drucker — die STL-Dateien reichen, mehr braucht niemand
- Online-Druckdienst (STL hochladen, Material PLA wählen)

### Schritt 3 — Slicen (STL → Druckdatei)

Ein Drucker kann STL nicht direkt drucken. Ein **Slicer** zerlegt das Modell in
Schichten und erzeugt die Druckdatei (G-Code). Kostenlos: PrusaSlicer, Bambu
Studio, Orca Slicer oder Cura — je nachdem, welcher Drucker es ist.

1. STL-Datei in den Slicer ziehen.
2. **Nicht drehen** — die Teile liegen schon richtig (große flache Seite unten,
   Frontplatten mit der Sichtseite nach unten).
3. Einstellungen:

| Einstellung | Wert |
|---|---|
| Material | **PLA** (am einfachsten zu drucken) |
| Düse | 0,4 mm (Standard) |
| Schichthöhe | 0,2 mm |
| Wände / Perimeter | 3 |
| Füllung (Infill) | 15–20 % |
| Stützstrukturen (Supports) | **aus** |
| Brim / Rand | aus. Nur beim großen Rückteil einschalten, falls sich die Ecken vom Bett lösen |

4. „Slicen“ klicken, Druckdatei auf den Drucker (USB-Stick, SD-Karte oder WLAN).
5. Die **erste Schicht beobachten**: Sie muss sauber am Bett haften. Bei der
   Frontplatte entstehen in der ersten Schicht die Gravuren („RFID“, „GAS“,
   Eckmarken).

### Schritt 4 — Einkaufsliste

| Anzahl | Teil | Wofür |
|---|---|---|
| 8 | Senkkopf-Schraube 3 × 12 mm (Spanplattenschraube oder M3 × 12) | Frontplatten an beide Gehäuse |
| 4 | Schraube 3 × 8 mm mit flachem Kopf (Linsenkopf) | Arduino Uno |
| 2 | Schraube M2 × 6 mm | HC-SR501 (alternativ Heißkleber) |
| 4 | Senkkopf-Holzschraube 3,5–4 mm + Dübel | Wandmontage (alternativ: Powerstrips / Montageklebeband) |
| 1 | 3-adriges Kabel, Länge je nach Weg (ca. 0,3 m durch die Wand, 1,5–2 m außen herum) + Dupont-Stecker | Verbindung zum Sensor |
| 1 | Mini-Breadboard 170 Kontakte (falls nicht vorhanden) | 5V/GND verteilen |
| 1 | USB-Netzteil 5 V + USB-B-Kabel | Stromversorgung |
| — | Heißklebepistole | Module fixieren |

### Schritt 5 — Zusammenbau

**Bedienteil:**

1. Frontplatte: Keypad-Folie abziehen, Flachkabel mit Stecker durch den
   Schlitz fädeln, Keypad an den vier Eckmarken ausrichten und festdrücken.
2. RC522 in die Eckführungen legen (flache Seite zur Front), mit zwei Punkten
   Heißkleber fixieren.
3. Buzzer in den Ring stecken, Heißkleber.
4. OLED zwischen die Führungen, Glas zur Front. Einschalten, das Bild im
   Fenster mittig schieben, dann erst festkleben.
5. Uno mit 4 Schrauben auf die Abstandshalter im Rückteil schrauben (Buchsen
   zeigen zu den Aussparungen unten).
6. Mini-Breadboard auf die Rückwand über dem Uno kleben (zwischen den beiden
   Montagelöchern).
7. Verkabeln wie bisher (Pin-Tabelle in [../CLAUDE.md](../CLAUDE.md)). Das
   Sensorkabel durch Kabelloch oder Kerbe hereinführen: 5V, GND, A2.
8. **Erst testen**, dann Frontplatte aufsetzen und mit 4 Schrauben festziehen.
   Nicht zu fest — Kunststoffgewinde überdreht leicht.

**Sensorteil:**

1. HC-SR501 mit der Linse durch die Öffnung stecken und mit 2 M2-Schrauben
   an die Zapfen schrauben (oder Heißkleber).
2. Tipp zu den Reglern: Haltezeit-Regler (Time) ganz gegen den Uhrzeigersinn
   = kürzeste Zeit (≈ 3 s), Jumper auf **H** (wiederholtes Auslösen).
3. Kabel anstecken (VCC, OUT, GND), durch das Loch oder die Kerbe führen,
   Frontplatte festschrauben.
4. Nach dem Einschalten braucht der HC-SR501 **etwa eine Minute zum
   Aufwärmen**, in der Zeit meldet er manchmal Bewegung. Bei der Vorführung
   einplanen.

**Montage:** Beide Rückteile zuerst an die Wand (Schraubenköpfe sitzen innen
versenkt), danach Elektronik rein und zuschrauben.

### Schritt 6 — Anpassen in OpenSCAD (nur wenn nötig)

Das Gehäuse ist in **OpenSCAD** gezeichnet — ein kostenloses CAD-Programm, in
dem das Modell als Text beschrieben wird. Deshalb lässt es sich über Zahlen
ändern, ohne zeichnen zu können.

1. OpenSCAD herunterladen: <https://openscad.org/downloads.html>
2. [../Gehaeuse/gehaeuse.scad](../Gehaeuse/gehaeuse.scad) öffnen.
3. Menü **Fenster → Customizer** einblenden. Dort stehen alle Maße als
   Eingabefelder, oben unter „Part selection“ wählt man das Teil.
4. Wert ändern, **F5** = schnelle Vorschau (`assembly` zeigt alles
   zusammengebaut mit den Modulen).
5. Zum Exportieren: ein Teil wählen (z. B. `control_front`), **F6** (Rendern,
   dauert ein paar Sekunden), dann **F7** bzw. *Datei → Export → STL*.

Die Gesamthöhe des Bedienteils berechnet sich automatisch aus Keypad, RFID und
OLED. Wird also z. B. `keypad_h` größer, wächst das Gehäuse mit.

### Offene Punkte / Annahmen

- Alle Modulmaße aus Datenblättern, **nicht am echten Aufbau gemessen**
  (siehe Schritt 1).
- Noch nicht gedruckt — die Passung (0,3 mm Spiel zwischen Front und Rückteil)
  ist ein üblicher Wert, kann aber je nach Drucker etwas zu stramm oder zu
  locker sein. Dann `clr` anpassen.
- Die Uno-Maße (Lochbild, Buchsen) sind die offiziellen Maße des Uno R3 und
  sollten stimmen.

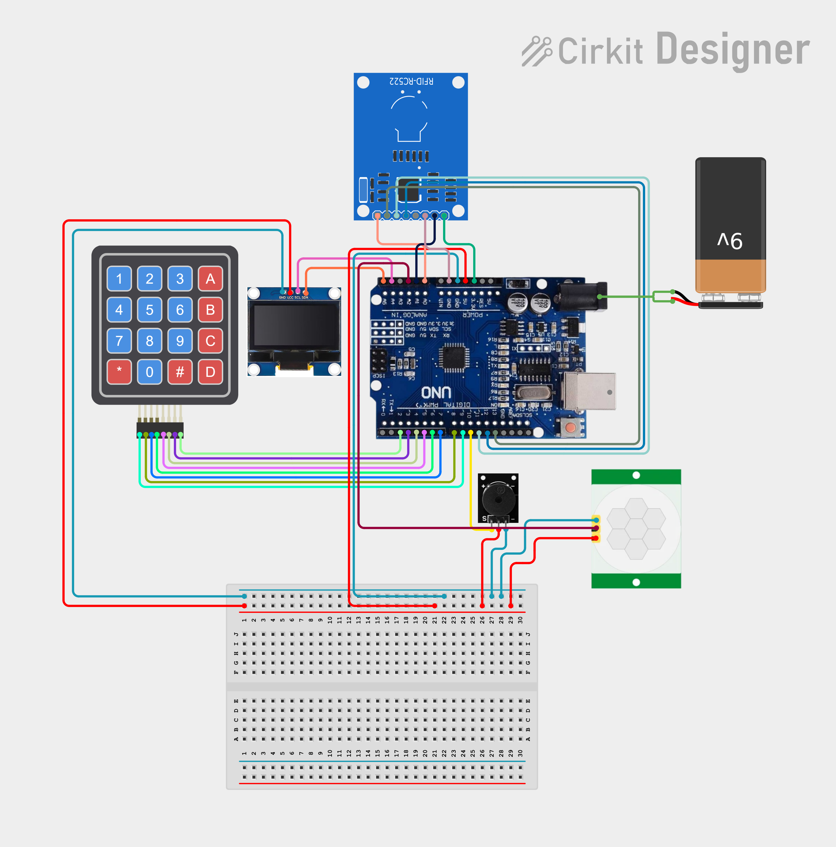
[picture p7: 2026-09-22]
Schaltplan/SCHALTPLAN.png

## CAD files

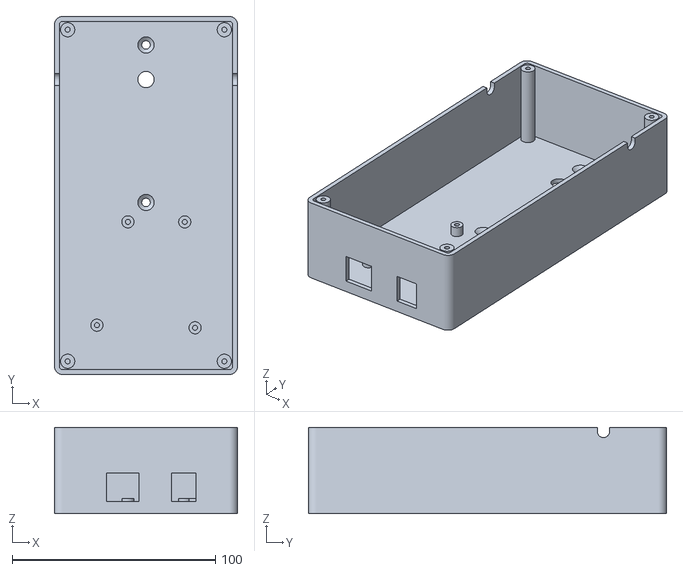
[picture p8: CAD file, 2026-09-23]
Gehaeuse/stl/control_back.stl
90.0 x 176.0 x 42.4

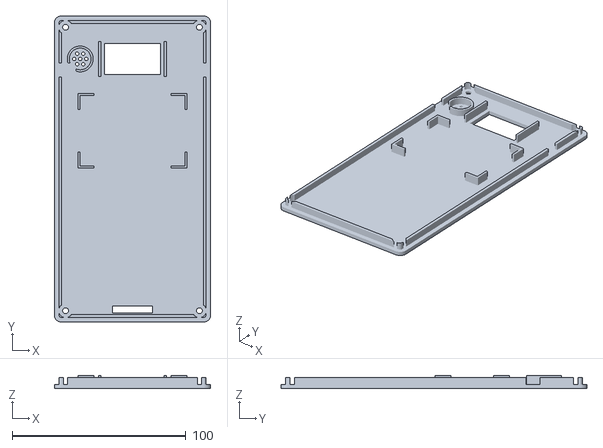
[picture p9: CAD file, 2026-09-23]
Gehaeuse/stl/control_front.stl
90.0 x 176.0 x 7.40

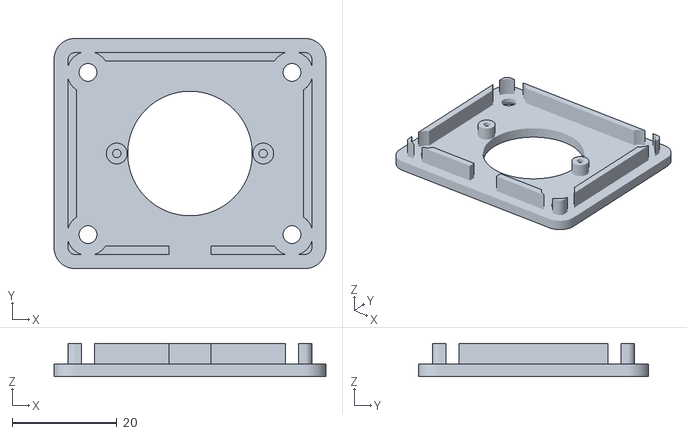
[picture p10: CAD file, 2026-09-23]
Gehaeuse/stl/sensor_front.stl
52.0 x 44.0 x 6.40

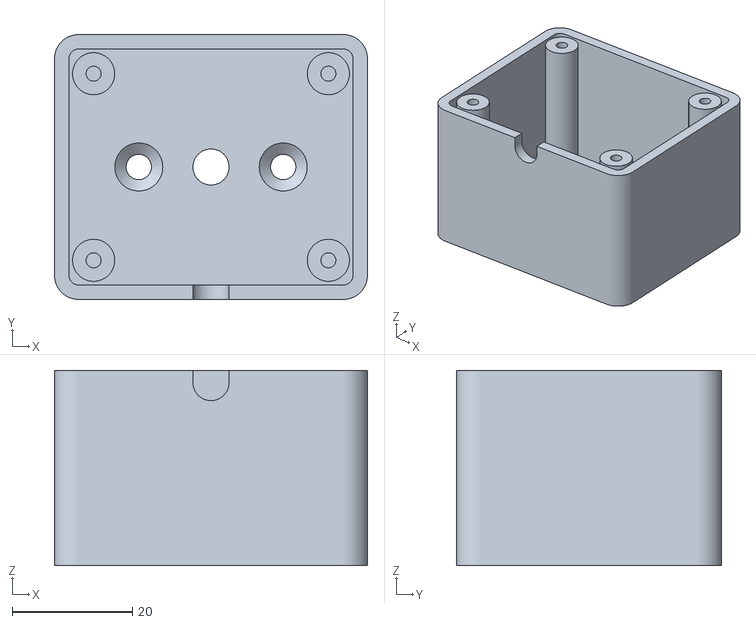
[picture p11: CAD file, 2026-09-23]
Gehaeuse/stl/sensor_back.stl
52.0 x 44.0 x 32.4

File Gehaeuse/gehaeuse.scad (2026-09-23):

// Enclosure for Projekt GAS (LF07)
//
// Two separate enclosures:
//   1. Control unit (outside, next to the door frame):
//      membrane keypad, OLED, RFID-RC522, passive buzzer, Arduino Uno
//   2. Sensor unit (inside the room): HC-SR501 motion sensor
//
// Usage (OpenSCAD, free: https://openscad.org):
//   - choose a value for "part" below (or in the Customizer panel)
//   - F6 = render, then File > Export > Export as STL
//   - all *_back / *_front parts are already in print orientation
//
// All sizes in mm. Values in the section "Measured parts" come from
// data sheets - check them with a ruler before printing.

/* [Part selection] */
part = "assembly"; // [assembly, exploded, sensor_assembly, control_back, control_front, sensor_back, sensor_front]

/* [General] */
wall = 2.4;           // side wall thickness (6 lines with a 0.4 nozzle)
floor_t = 2.4;        // back plate thickness
lid_t = 2.4;          // front plate thickness
corner_r = 4;         // outer corner radius
clr = 0.3;            // gap between lid lip and walls
lip_t = 1.6;          // thickness of the lid lip
lip_h = 4;            // height of the lid lip
boss_d = 7;           // screw boss diameter
boss_inset = 6.5;     // screw boss centre, measured from the outer edge
pilot_d = 2.5;        // pilot hole for 3 mm screws
screw_d = 3.4;        // clearance hole for 3 mm screws
csk_d = 6.4;          // countersink diameter for the lid screws
wall_screw_d = 4.2;   // wall mounting screws (up to 4 mm)
wall_csk_d = 8;
guide_t = 1.2;        // thickness of the positioning guides
guide_h = 5;          // height of the positioning guides
fit = 0.25;           // play per side around modules
engrave = 0.6;        // depth of the engravings on the front

/* [Control unit] */
cu_w = 90;            // outer width
cu_depth = 40;        // inner depth (back plate to lid)

/* [Measured parts - check with a ruler!] */
keypad_w = 69.5;      // membrane keypad without ribbon
keypad_h = 77;
ribbon_slot_w = 23;   // must let the 8-pin plug through
ribbon_slot_h = 4;
rfid_w = 60;          // RC522 board
rfid_h = 40;
oled_w = 36;          // 1.3" SH1106 board
oled_h = 34;
oled_win_w = 32;      // window, active area is about 29.4 x 14.7
oled_win_h = 18;
buzzer_d = 12;        // buzzer body on the KY-006 style module
uno_standoff_h = 5;

/* [Sensor unit] */
su_w = 52;
su_h = 44;
su_depth = 30;        // inner depth, room for the plugs under the sensor
pir_w = 32.3;         // HC-SR501 board
pir_h = 24.3;
pir_hole_dist = 28;   // distance of the two mounting holes
pir_dome_d = 23;      // Fresnel lens diameter
pir_post_h = 3;       // gap between lid and sensor board

$fn = 48;

// ---------------------------------------------------------------------------
// Derived layout of the control unit
// Front view, origin = bottom-left outer corner, x right, y up, z to the front
// ---------------------------------------------------------------------------

UNO_W = 53.34;
UNO_L = 68.58;
// Uno mounting holes, board upright with the USB/power jacks at the bottom
UNO_HOLES = [[2.54, 15.24], [17.78, 66.04], [45.72, 66.04], [50.8, 13.97]];

lip_in = wall + clr + lip_t;          // outer edge -> inner side of the lip
cu_cx = cu_w / 2;
slot_y = lip_in + 0.8;                // ribbon slot directly below the keypad
kp_x = cu_cx - keypad_w / 2;
kp_y = slot_y + ribbon_slot_h;
rfid_cy = kp_y + keypad_h + 4 + rfid_h / 2;
oled_cy = rfid_cy + rfid_h / 2 + 3 + guide_t + oled_h / 2;
cu_h = ceil(oled_cy + oled_h / 2 + 3 + lip_in);
cu_th = floor_t + cu_depth;           // height of the back part
buzzer_x = (cu_cx + oled_w / 2 + fit + guide_t + cu_w - lip_in) / 2;

uno_x = cu_cx - UNO_W / 2;
uno_y = wall + 6.2 + 0.4;             // USB jack sticks out 6.2 mm
uno_z = floor_t + uno_standoff_h;

mount_y = [uno_y + UNO_L + 7, cu_h - 14];
cable_y = 145;
notch_w = 6;
notch_d = 5;

su_th = floor_t + su_depth;

// ---------------------------------------------------------------------------
// Helpers
// ---------------------------------------------------------------------------

module rrect(w, h, r) {
    translate([r, r]) offset(r = r) square([w - 2 * r, h - 2 * r]);
}

// rounded rectangle shrunk by d on every side
module rrect_inset(w, h, r, d) {
    translate([d, d]) rrect(w - 2 * d, h - 2 * d, max(r - d, 0.5));
}

function boss_pos(w, h) = [
    [boss_inset, boss_inset], [w - boss_inset, boss_inset],
    [boss_inset, h - boss_inset], [w - boss_inset, h - boss_inset]
];

// countersunk hole, head at z = top
module csk_hole(d, dk, top) {
    cone_h = (dk - d) / 2;
    translate([0, 0, -1]) cylinder(d = d, h = top + 2);
    translate([0, 0, top - cone_h]) cylinder(d1 = d, d2 = dk, h = cone_h + 0.01);
    translate([0, 0, top]) cylinder(d = dk, h = 50);
}

// open box: back plate, walls and four screw bosses
module shell_back(w, h, th) {
    difference() {
        union() {
            difference() {
                linear_extrude(th) rrect(w, h, corner_r);
                translate([0, 0, floor_t])
                    linear_extrude(th) rrect_inset(w, h, corner_r, wall);
            }
            intersection() {
                linear_extrude(th) rrect(w, h, corner_r);
                for (p = boss_pos(w, h))
                    translate(p) cylinder(d = boss_d, h = th);
            }
        }
        for (p = boss_pos(w, h))
            translate([p[0], p[1], th - 12]) cylinder(d = pilot_d, h = 13);
    }
}

// lid: plate (z = 0 .. lid_t, front face on top) and lip hanging down
module shell_front(w, h) {
    difference() {
        union() {
            linear_extrude(lid_t) rrect(w, h, corner_r);
            translate([0, 0, -lip_h]) linear_extrude(lip_h) difference() {
                rrect_inset(w, h, corner_r, wall + clr);
                rrect_inset(w, h, corner_r, wall + clr + lip_t);
                for (p = boss_pos(w, h)) translate(p) circle(d = boss_d + 1);
            }
        }
        for (p = boss_pos(w, h))
            translate([p[0], p[1], -lip_h]) csk_hole(screw_d, csk_d, lip_h + lid_t);
    }
}

// cut a cable notch into the rim of a wall (x/y = centre of the notch)
module rim_notch(x, y, horizontal, th) {
    translate([x, y, th - notch_d + notch_w / 2]) {
        rotate(horizontal ? [90, 0, 0] : [0, 90, 0])
            cylinder(d = notch_w, h = 20, center = true);
        translate([0, 0, 25]) cube([horizontal ? notch_w : 20, horizontal ? 20 : notch_w, 50], center = true);
    }
}

// remove the lid lip where a rim notch is (x/y = centre of the notch)
module lip_cut(x, y, horizontal) {
    translate([x, y, -lip_h / 2 - 0.5])
        cube([horizontal ? notch_w + 2 : 20, horizontal ? 20 : notch_w + 2, lip_h + 1], center = true);
}

// four L-shaped corner guides around a w x h pocket, hanging below z = 0
module corner_guides(w, h, leg = 8) {
    pw = w + 2 * fit;
    ph = h + 2 * fit;
    translate([0, 0, -guide_h]) linear_extrude(guide_h) difference() {
        square([pw + 2 * guide_t, ph + 2 * guide_t], center = true);
        square([pw, ph], center = true);
        square([pw - 2 * leg, ph + 10], center = true);
        square([pw + 10, ph - 2 * leg], center = true);
    }
}

// line drawing of a rounded rectangle (for engravings)
module rrect_line(w, h, r, lw) {
    difference() {
        translate([-w / 2, -h / 2]) rrect(w, h, r);
        translate([-w / 2, -h / 2]) rrect_inset(w, h, r, lw);
    }
}

// L-shaped corner mark, legs pointing along +x and +y
module corner_mark(leg = 5, lw = 0.8) {
    square([leg, lw]);
    square([lw, leg]);
}

// ---------------------------------------------------------------------------
// Control unit
// ---------------------------------------------------------------------------

module control_back() {
    difference() {
        union() {
            shell_back(cu_w, cu_h, cu_th);
            // Uno standoffs
            for (p = UNO_HOLES)
                translate([uno_x + p[0], uno_y + p[1], 0])
                    cylinder(d = 6, h = uno_z);
        }
        // pilot holes for the Uno screws (deep enough for 3 x 8 mm)
        for (p = UNO_HOLES)
            translate([uno_x + p[0], uno_y + p[1], 0.8])
                cylinder(d = pilot_d, h = uno_z);
        // USB-B and power jack openings in the bottom wall
        translate([uno_x + 9.34 + 6 - 8, -1, uno_z - 1.5]) cube([16, wall + 2, 14]);
        translate([uno_x + 40.7 + 4.5 - 6, -1, uno_z - 1.5]) cube([12, wall + 2, 14]);
        // wall mounting holes, screw heads inside
        for (y = mount_y)
            translate([cu_cx, y, 0]) csk_hole(wall_screw_d, wall_csk_d, floor_t);
        // cable hole through the back (cable through the wall)
        translate([cu_cx, cable_y, -1]) cylinder(d = 8, h = floor_t + 2);
        // cable notches in both side walls (cable on the wall surface)
        rim_notch(wall / 2, cable_y, false, cu_th);
        rim_notch(cu_w - wall / 2, cable_y, false, cu_th);
    }
}
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

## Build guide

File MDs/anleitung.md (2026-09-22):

<!--
Prompt für Claude (claude.ai): Erstelle aus dem folgenden Inhalt eine kurze,
einfache PDF-Bedienungsanleitung (1 Seite, wenn möglich). Zielgruppe sind
Endnutzer des Sicherheitssystems, keine Techniker - klar, kurz, ohne
Code-Details. Gerne mit den Symbolen (Herz/Totenkopf) als einfache Icons oder
Beschreibung, sauber gegliedert mit den Abschnitten unten als
Überschriften/Tabelle.
-->

# Bedienungsanleitung — Mini-Sicherheitssystem

Kleines Zugangs-/Alarmsystem mit Keypad, Display und RFID-Kartenleser.

## Anzeige

| Symbol | Bedeutung |
|---|---|
| ❤️ Herz | Unscharf — Anlage ist aus |
| 💀 Totenkopf (steht) | Scharf, oder Ausgangsverzögerung läuft |
| 💀 Totenkopf (blinkt) | ALARM |
| ✖️ Kreuz (kurz) | Falsche PIN oder unbekannte Karte |

## Scharf- / Unscharfschalten

**Mit PIN-Code:**
1. PIN über das Tastenfeld eingeben (erscheint als `*`)
2. Mit `#` bestätigen
3. Bei falscher Eingabe: `*` löscht die Eingabe und man kann neu beginnen

**Mit Chipkarte:**
- Karte einfach an den Kartenleser halten — fertig

Beide Wege funktionieren identisch: aus dem unscharfen Zustand schalten sie
scharf, aus scharf/Alarm schalten sie wieder unscharf.

Nach dem Scharfschalten bleiben **10 Sekunden Zeit**, um den Raum zu
verlassen (kurzes Piepen), bevor die Anlage wirklich scharf ist.

## Alarm

- Der Alarm löst aus bei Bewegung (nur im scharfen Zustand) oder nach
  **3 falschen** PIN-Eingaben bzw. unbekannten Karten.
- Der Alarm dauert 30 Sekunden oder endet sofort mit der richtigen PIN oder
  einer bekannten Karte.

## Neue Karten hinzufügen oder löschen

Karten werden direkt am Gerät verwaltet — dafür ist kein PC nötig.

1. Im unscharfen Zustand Taste **A** drücken
2. Die Admin-PIN eingeben und mit `#` bestätigen
3. Im Menü:
   - **1** = neue Karte anlernen → Karte an den Leser halten
   - **2** = gespeicherte Karten durchblättern (`#`) oder löschen (`D`)
   - **\*** = Menü verlassen

Das Menü schließt sich nach 20 Sekunden ohne Tastendruck automatisch.

## Wichtig

- PIN-Code und Admin-PIN nicht weitergeben.
- Die Admin-PIN ermöglicht das Anlernen neuer Karten — entsprechend
  vertraulich behandeln.

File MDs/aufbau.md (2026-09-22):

# Arduino Security/Access Circuit — Project Specification

## Purpose

Use this document as the authoritative hardware specification for writing the complete Arduino firmware for this project with Claude Code.

The firmware must be based only on the components, pins, and wiring documented here. Do not invent components, pins, sensors, display controllers, keypad layouts, I²C addresses, or system behavior without clearly identifying the assumption.

Before writing final code, identify any missing hardware information and verify suspicious or nonstandard wiring.

---

## Project Status (updated 2026-09-15)

This document was the original hardware export, written before the firmware
existed and before the RFID reader was added. It has since been updated to
match the finished build. **For anything not covered here, the pin table in
[../CLAUDE.md](../CLAUDE.md) is authoritative.**

- Microcontroller: Arduino Uno R3
- Firmware status: complete, see [../Code/alarm_system/alarm_system.ino](../Code/alarm_system/alarm_system.ino).
- The project now also includes an RFID-RC522 reader (see component 6 below)
  as a second way to arm/disarm, alongside the keypad PIN.
- The motion sensor was moved from Pin 11 to **Pin A2**, because Pin 11 is the
  hardware SPI MOSI line needed by the RC522.
- The OLED I²C pins were originally recorded reversed (SDA on A5, SCL on A4).
  The real build uses the Uno's fixed hardware I²C pins correctly: **SDA = A4,
  SCL = A5**. The wiring table below reflects the corrected, actual wiring.

---

## Components

### 1. Arduino Uno R3

- Component name: `Arduino Uno R3`
- Instance label: `Arduino Uno R3`
- Instance ID: `062c9730-3b06-46d1-a97e-57ef584a5b23`
- Component version: `1`
- Unique ID: `817afc45-76de-4b7c-9dca-7b77c4e86f9e`

Available pins recorded in the project:

- Serial Clock Line
- Serial Data Line
- Analog Reference
- Ground
- Pin 13
- Pin 12
- Pin 11
- Pin 10
- Pin 9
- Pin 8
- Pin 7
- Pin 6
- Pin 5
- Pin 4
- Pin 3
- Pin 2
- Transmit / Pin 1
- Receive / Pin 0
- Pin A5
- Pin A4
- Pin A3
- Pin A2
- Pin A1
- Pin A0
- External voltage input
- Ground 2
- Ground 1
- 5 Volt
- 3.3 Volt
- Reset

---

### 2. Motion Sensor

- Component name: `motion sensor`
- Instance label: `motion sensor`
- Instance ID: `c31ed2dc-87bd-4d83-8258-bb4ba6429fcf`
- Component version: `3`
- Unique ID: `784cc7d2-816e-4aa1-9822-731976238642`

Pins:

- `GND`
- `OUT`
- `VCC`

The exact motion sensor model is not specified.

**Update:** `OUT` now connects to Uno pin **A2** instead of Pin 11 (freed up
for the RC522's hardware SPI MOSI line). `A2` is simply digital pin 16 on the
Uno and works normally with `digitalRead()`. OUT is active HIGH when motion
is detected.

---

### 3. 4x4 Keypad

- Component name: `4x4 Keypad`
- Instance label: `4x4 Keypad`
- Instance ID: `748425ae-fc0d-44f4-b68e-b193353719c1`
- Component version: `3`
- Unique ID: `eec1bde3-86a8-4ac8-81a4-99525bb4829f`

Pins:

- `R1`
- `R2`
- `R3`
- `R4`
- `C1`
- `C2`
- `C3`
- `C4`

The physical key layout and library-specific keypad mapping are not specified.

---

### 4. OLED Display

- Component name: `oled`
- Instance label: `oled`
- Instance ID: `79e9f97f-990f-47c9-8a24-aa2966888a1f`
- Component version: `1`
- Unique ID: `80eff8b9-9492-4dbe-85ad-05da03fe76af`

Pins:

- `GND`
- `VCC`
- `SCL`
- `SDA`

**Update:** Verified as an SH1106-based 128x64 module at I²C address `0x3C`,
using the `Adafruit_SH1106G` library (not SSD1306). `SDA` connects to **A4**
and `SCL` to **A5** — the Uno's fixed hardware I²C pins.

---

### 5. Passive Buzzer

- Component name: `Buzzer Passive`
- Instance label: `Buzzer Passive`
- Instance ID: `b10ea444-40cf-4c9b-9fb3-a80931e5396f`
- Component version: `1`
- Unique ID: `7f4e8101-f6ea-4a9f-abea-db3207b54942`

Pins:

- `S output signal`
- `+VCC`
- `GND`

No resistor, transistor, or external buzzer driver is present in the documented circuit.

---

### 6. RFID-RC522 Reader

Added after this document's original export, so it has no Cirkit Designer
instance/unique ID. Provides a second way to arm/disarm: holding a card
listed in `ALLOWED_UIDS` does the same as entering the correct PIN.

Pins:

- `SDA` / `SS`
- `SCK`
- `MOSI`
- `MISO`
- `IRQ` (not connected)
- `GND`
- `RST`
- `VCC`

Runs on **3.3V, not 5V** — 5V on VCC destroys the module. `SCK`/`MOSI`/`MISO`
are the Uno's fixed hardware SPI pins (D13/D11/D12) and are shared with no
other component. `VersionReg` answers `0x91` or `0x92` on a genuine module;
`0x00` or `0xFF` means it is not responding (wiring or wrong voltage).

---

## Complete Wiring Table

### Arduino Uno Pin Assignments

| Arduino Uno pin | Connected component | Component pin | Signal/function |
|---|---|---|---|
| Pin 2 | 4x4 Keypad | C4 | Keypad column |
| Pin 3 | 4x4 Keypad | C3 | Keypad column |
| Pin 4 | 4x4 Keypad | C2 | Keypad column |
| Pin 5 | 4x4 Keypad | C1 | Keypad column |
| Pin 6 | 4x4 Keypad | R4 | Keypad row |
| Pin 7 | 4x4 Keypad | R3 | Keypad row |
| Pin 8 | 4x4 Keypad | R2 | Keypad row |
| Pin 9 | 4x4 Keypad | R1 | Keypad row |
| Pin 10 | Passive Buzzer | S output signal | Buzzer control signal |
| Pin 11 | RFID-RC522 | MOSI | Hardware SPI (fixed) |
| Pin 12 | RFID-RC522 | MISO | Hardware SPI (fixed) |
| Pin 13 | RFID-RC522 | SCK | Hardware SPI (fixed) |
| Pin A0 | RFID-RC522 | SDA / SS | Chip select |
| Pin A1 | RFID-RC522 | RST | Reset |
| Pin A2 | Motion sensor | OUT | Motion detection signal (moved off Pin 11) |
| Pin A4 | OLED | SDA | Fixed Uno I2C data pin |
| Pin A5 | OLED | SCL | Fixed Uno I2C clock pin |
| 5 Volt | Shared positive rail | OLED VCC, Buzzer +VCC, Motion VCC, Keypad (unpowered) | +5 V supply |
| 3.3 Volt | RFID-RC522 | VCC | +3.3 V supply — NOT 5V |
| Ground 1 | Shared ground rail | OLED GND, Buzzer GND, Motion GND, RFID-RC522 GND | Common ground |

---

## Keypad Wiring

The 4x4 keypad is connected directly to Arduino digital pins 2 through 9.

### Keypad Column Connections

| Keypad pin | Arduino pin |
|---|---|
| `C1` | Pin 5 |
| `C2` | Pin 4 |
| `C3` | Pin 3 |
| `C4` | Pin 2 |

### Keypad Row Connections

| Keypad pin | Arduino pin |
|---|---|
| `R1` | Pin 9 |
| `R2` | Pin 8 |
| `R3` | Pin 7 |
| `R4` | Pin 6 |

### Keypad Firmware Notes

The firmware must use the following raw pin mapping unless the physical wiring is intentionally changed:

```cpp
const byte ROW_PINS[4] = {9, 8, 7, 6};
const byte COL_PINS[4] = {5, 4, 3, 2};
```

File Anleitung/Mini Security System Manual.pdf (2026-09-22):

### // SICHERHEITSSYSTEM · BEDIENUNGSANLEITUNG

# Mini-Sicherheitssystem

Kleines Zugangs-/Alarmsystem mit Keypad, Display und RFID-Kartenleser.

## 01 ANZEIGE

S Y M B O L | B E D E U T U N G

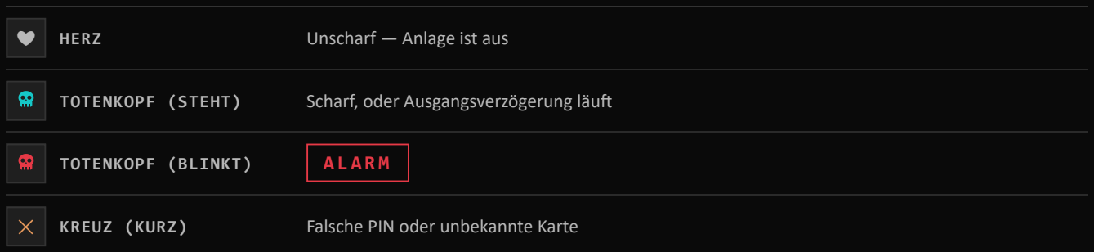
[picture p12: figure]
HERZ; Unscharf — Anlage ist aus; TOTENKOPF (STEHT); Scharf, oder Ausgangsverzögerung läuft; TOTENKOPF (BLINKT); ✕ KREUZ (KURZ); Falsche PIN oder unbekannte Karte
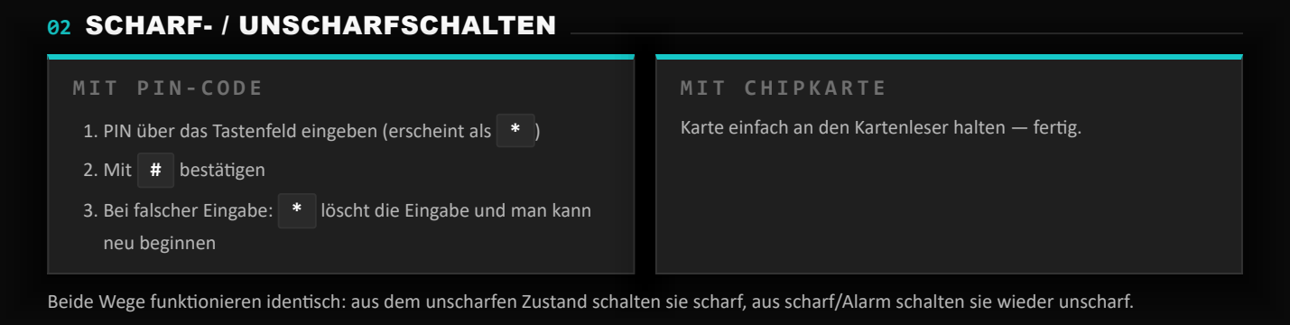
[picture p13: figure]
02 SCHARF- / UNSCHARFSCHALTEN; 2. Mit # bestätigen; neu beginnen

1. PIN über das Tastenfeld eingeben (erscheint als * )
3. Bei falscher Eingabe: * löscht die Eingabe und man kann

Karte einfach an den Kartenleser halten — fertig.

Beide Wege funktionieren identisch: aus dem unscharfen Zustand schalten sie scharf, aus scharf/Alarm schalten sie wieder unscharf. Nach dem Scharfschalten bleiben 10 Sekunden Zeit, um den Raum zu verlassen (kurzes Piepen), bevor die Anlage wirklich scharf ist.

## 03 ALARM

Der Alarm löst aus bei Bewegung (nur im scharfen Zustand) oder nach 3 falschen PIN-Eingaben bzw. unbekannten Karten. Der Alarm dauert 30 Sekunden oder endet sofort mit der richtigen PIN oder einer bekannten Karte.

## 04 NEUE KARTEN HINZUFÜGEN ODER LÖSCHEN

Karten werden direkt am Gerät verwaltet — dafür ist kein PC nötig.
1. Im unscharfen Zustand Taste A drücken
2. Die Admin-PIN eingeben und mit # bestätigen
3. Im Menü:
1 = neue Karte anlernen → Karte an den Leser halten
2 = gespeicherte Karten durchblättern ( # ) oder löschen ( D )
* = Menü verlassen
Das Menü schließt sich nach 20 Sekunden ohne Tastendruck automatisch.
Taste B (im unscharfen Zustand) = RFID-Reset: startet den Kartenleser neu — hilfreich, falls Karten plötzlich nicht mehr erkannt werden.

## 05 WICHTIG

PIN-Code und Admin-PIN nicht weitergeben.
Die Admin-PIN ermöglicht das Anlernen neuer Karten — entsprechend vertraulich behandeln.

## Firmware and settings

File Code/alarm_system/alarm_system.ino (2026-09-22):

/*
 * alarm_system.ino
 * Mini access / alarm system for the LF07 project (see MDs/aufbau.md).
 *
 * Behaviour
 *   - DISARMED  : heart icon on the OLED, motion sensor is ignored.
 *   - EXIT DELAY: skull + countdown, time to leave the room after arming.
 *   - ARMED     : skull icon, motion on the sensor triggers the alarm.
 *   - ALARM     : flashing skull + countdown, loud siren for 30 s
 *                 (or until the PIN is entered / a known card is presented).
 *
 * Two ways to arm and disarm
 *   Keypad : PIN + '#'
 *   RFID   : hold a known card (see "RFID admin menu" below) to the reader
 *   Both toggle the same way: disarmed -> exit delay -> armed, and armed or
 *   alarm -> disarmed. Three wrong PINs or unknown cards raise the alarm.
 *
 * Keypad
 *   0-9  enter PIN digits (shown as '*' only)
 *   #    confirm
 *   *    clear the current entry
 *   A    while disarmed and idle: enter the admin PIN to open the admin menu
 *   B    while disarmed: soft-reset the RFID reader (see resetRfid() below -
 *        the RC522 clones can occasionally stop answering over SPI)
 *   C-D  unused
 *
 * RFID admin menu (Keypad 'A' + ADMIN_PIN + '#', only while disarmed)
 *   Cards are no longer hard-coded: they live in the Uno's internal EEPROM,
 *   so they survive re-uploading the sketch and can be managed without a PC.
 *     1  add a card   - hold the new card to the reader
 *     2  list / delete cards - '#' next, 'D' delete shown card, '*' back
 *     *  leave the admin menu
 *   A wrong admin PIN counts as a wrong try, same as a wrong PIN_CODE.
 *   The menu times out back to normal operation after ADMIN_IDLE_TIMEOUT_MS.
 *
 * Feedback tones (passive buzzer on D10)
 *   accepted    : two short bright notes
 *   rejected    : rough low buzz, 3 s
 *   3x rejected : full alarm
 *
 * A wrong PIN or unknown card also shows a brief X icon on the OLED for the
 * length of the rejected-buzz, on top of whatever else is on screen.
 *
 * Wiring (see CLAUDE.md - changed when the RFID reader was added)
 *   Keypad rows R1..R4 -> D9, D8, D7, D6
 *   Keypad cols C1..C4 -> D5, D4, D3, D2
 *   Passive buzzer     -> D10
 *   Motion sensor OUT  -> A2  (active HIGH; moved off D11, that is SPI MOSI)
 *   OLED SH1106 128x64 -> SDA = A4, SCL = A5, I2C address 0x3C
 *   RC522 SS -> A0, RST -> A1, MOSI -> D11, MISO -> D12, SCK -> D13
 *   RC522 VCC -> 3.3V, NOT 5V
 *
 * MEMORY NOTE
 *   The Uno has 2048 bytes of SRAM and the OLED frame buffer alone takes 1024.
 *   With the Keypad library on top only ~205 bytes were left, which is not
 *   enough once tone() interrupts hit while the display code is deep in the
 *   stack - the result were random resets and corrupted key input. This sketch
 *   therefore scans the keypad itself (see scanKeypad()) and keeps every string
 *   in flash. The MFRC522 library costs about 15 bytes of static SRAM (mostly
 *   the Uid struct), so there is still room; setup() prints the free SRAM and
 *   it should stay well above 250.
 *
 * Libraries: Adafruit SH110X, Adafruit GFX, MFRC522, SPI, EEPROM
 *            (Keypad library NOT needed)
 * Serial Monitor: 9600 baud
 */

#include <Wire.h>
#include <SPI.h>
#include <EEPROM.h>
#include <Adafruit_GFX.h>
#include <Adafruit_SH110X.h>
#include <MFRC522.h>

// ---------------------------------------------------------------------------
// Settings - change these if needed
// ---------------------------------------------------------------------------
const char PIN_CODE[]  = "55559";                 // access code
const char ADMIN_PIN[] = "19283";                 // opens the RFID admin menu

const unsigned long ALARM_MS         = 30000UL;  // siren length
const unsigned long ERROR_TONE_MS    = 2000UL;   // wrong-PIN buzz length
const unsigned long EXIT_DELAY_MS    = 10000UL;  // time to leave after arming
const unsigned long ENTRY_TIMEOUT_MS = 10000UL;  // clear a half-typed PIN
const unsigned long ADMIN_IDLE_TIMEOUT_MS = 20000UL; // leave admin menu if idle
const unsigned long ADMIN_MSG_MS     = 1500UL;   // "Saved" / "Full" ... display time
const byte MAX_WRONG_TRIES = 3;                  // wrong tries before alarm
const byte MAX_ENTRY_LEN   = 8;                  // keypad input buffer
const byte DEBOUNCE_MS     = 20;                 // keypad debounce

// RFID cards that may arm / disarm the system are no longer hard-coded here:
// they are stored in the Uno's internal EEPROM and managed from the admin
// menu (keypad 'A' + ADMIN_PIN + '#'), see the UID storage section further
// down. DEFAULT_UIDS is only the factory list written to EEPROM the very
// first time the sketch runs on a blank chip - after that, edit cards from
// the menu, not here.
// These are 4-byte UIDs (MIFARE Classic cards and key fobs). If rfid_test
// reports 7 bytes instead, set UID_LEN to 7 and use 7 bytes per row.
const byte UID_LEN = 4;
const byte DEFAULT_UIDS[][UID_LEN] PROGMEM = {
  {0x9C, 0xEB, 0x1F, 0x49},   // key fob <-- REPLACE with your own UID
};
const byte DEFAULT_UID_COUNT = sizeof(DEFAULT_UIDS) / UID_LEN;

// EEPROM-backed UID storage. Deliberately small: the OLED frame buffer
// already eats most of the Uno's 2048 byte SRAM (see MEMORY NOTE above), and
// the school setup never needs more than a handful of cards.
const byte MAX_STORED_UIDS = 8;
const int  EEPROM_MAGIC_ADDR = 0;
const int  EEPROM_COUNT_ADDR = 1;
const int  EEPROM_DATA_ADDR  = 2;
const byte EEPROM_MAGIC = 0xA5;

byte storedUids[MAX_STORED_UIDS][UID_LEN];
byte storedUidCount = 0;

// How often the reader is polled. A poll with no card in front of it blocks
// for ~25 ms (the RC522 answer timeout), so polling on every loop pass would
// slow down the keypad and make the siren sweep choppy.
const unsigned long RFID_POLL_MS = 200UL;

// ---------------------------------------------------------------------------
// Pins
// ---------------------------------------------------------------------------
const byte ROW_PINS[4] = {9, 8, 7, 6};   // R1, R2, R3, R4
const byte COL_PINS[4] = {5, 4, 3, 2};   // C1, C2, C3, C4
const byte BUZZER_PIN = 10;
const byte MOTION_PIN = A2;              // moved: D11 is now SPI MOSI
const byte RFID_SS_PIN  = A0;            // RC522 SDA / SS
const byte RFID_RST_PIN = A1;            // RC522 RST
// SPI itself is fixed on the Uno: MOSI = D11, MISO = D12, SCK = D13

// keymap lives in flash - the Keypad library needed it in RAM
const char KEYS[4][4] PROGMEM = {
  {'1', '2', '3', 'A'},
  {'4', '5', '6', 'B'},
  {'7', '8', '9', 'C'},
  {'*', '0', '#', 'D'}
};

// ---------------------------------------------------------------------------
// OLED
// ---------------------------------------------------------------------------
#define SCREEN_WIDTH  128
#define SCREEN_HEIGHT 64
#define OLED_RESET    -1
#define OLED_ADDRESS  0x3C
Adafruit_SH1106G display(SCREEN_WIDTH, SCREEN_HEIGHT, &Wire, OLED_RESET);
bool oledOk = false;

// ---------------------------------------------------------------------------
// RFID reader
// ---------------------------------------------------------------------------
MFRC522 mfrc522(RFID_SS_PIN, RFID_RST_PIN);
bool rfidOk = false;
unsigned long lastRfidPoll = 0;

// ---------------------------------------------------------------------------
// State
// ---------------------------------------------------------------------------
enum SystemState { STATE_DISARMED, STATE_EXIT_DELAY, STATE_ARMED, STATE_ALARM, STATE_ADMIN };
SystemState state = STATE_DISARMED;

char entry[MAX_ENTRY_LEN + 1];
byte entryLen = 0;
unsigned long lastKeyMs = 0;
bool enteringAdmin = false;     // current entry[] is an admin PIN, not PIN_CODE

byte wrongTries = 0;
unsigned long stateStart = 0;   // start of exit delay / alarm
bool lastMotion = false;        // for rising-edge detection
bool displayDirty = true;

// ---------------------------------------------------------------------------
// Admin menu state (RFID cards, see uidAllowed()/addUid()/deleteUidAt())
// ---------------------------------------------------------------------------
enum AdminScreen { ADMIN_MENU, ADMIN_ADD_WAIT, ADMIN_LIST };
AdminScreen adminScreen = ADMIN_MENU;
byte adminListIndex = 0;
unsigned long lastAdminKeyMs = 0;
const __FlashStringHelper *adminMsg = nullptr;
unsigned long adminMsgUntil = 0;
unsigned long lastDraw = 0;

// Sound engine (non-blocking, so the keypad keeps working during a tone)
enum SoundId { SOUND_NONE, SOUND_OK, SOUND_ERROR, SOUND_ALARM };
SoundId sound = SOUND_NONE;
unsigned long soundStart = 0;
int currentFreq = -1;

void setup() {
  Serial.begin(9600);

  // SPI has to come up before the buzzer pin is set: SPI.begin() forces D10
  // (the AVR hardware SS pin) to OUTPUT HIGH, and D10 is our buzzer. Setting
  // the buzzer low afterwards leaves it in a defined, silent state.
  SPI.begin();
  mfrc522.PCD_Init();

  setupKeypad();
  pinMode(MOTION_PIN, INPUT);
  pinMode(BUZZER_PIN, OUTPUT);
  digitalWrite(BUZZER_PIN, LOW);

  entry[0] = '\0';

  oledOk = display.begin(OLED_ADDRESS, true);
  if (oledOk) {
    display.clearDisplay();
    display.display();
  } else {
    Serial.println(F("[OLED] not found - check SDA=A4 / SCL=A5 and address 0x3C"));
  }

  // VersionReg answers 0x91 / 0x92 on a genuine RC522. 0x00 or 0xFF means the
  // reader is not answering - wiring, or 5 V instead of 3.3 V on VCC.
  byte ver = mfrc522.PCD_ReadRegister(MFRC522::VersionReg);
  rfidOk = (ver != 0x00 && ver != 0xFF);
  Serial.print(F("[RFID] version 0x"));
  Serial.println(ver, HEX);
  if (!rfidOk) {
    Serial.println(F("[RFID] reader not found - check SS=A0, RST=A1 and 3.3V"));
    Serial.println(F("[RFID] keypad still works"));
  }

  loadUidsFromEeprom();

  Serial.println(F("=== Alarm system ready (disarmed) ==="));
  Serial.println(F("PIN + '#' or a known RFID card arms / disarms."));
  Serial.print(F("stored RFID cards: "));
  Serial.println(storedUidCount);
  Serial.print(F("free SRAM: "));
  Serial.println(freeRam());

  lastMotion = (digitalRead(MOTION_PIN) == HIGH);
  displayDirty = true;
}

void loop() {
  if (state == STATE_ADMIN) {
    handleAdminKeypad();
    handleAdminRfid();
  } else {
    handleKeypad();
    handleRfid();
  }
  handleMotion();
  updateState();
  updateSound();
  updateDisplay();
}

// free SRAM in bytes - if this gets close to 0 the frame buffer gets corrupted
int freeRam() {
  extern int __heap_start, *__brkval;
  int v;
  return (int)&v - (__brkval == 0 ? (int)&__heap_start : (int)__brkval);
}

// ---------------------------------------------------------------------------
// Keypad - own matrix scan instead of the Keypad library (saves ~120 byte RAM)
// ---------------------------------------------------------------------------
void setupKeypad() {
  for (byte i = 0; i < 4; i++) {
    pinMode(ROW_PINS[i], INPUT_PULLUP);
    digitalWrite(COL_PINS[i], LOW);   // set the level first, then release the
    pinMode(COL_PINS[i], INPUT);      // pin - avoids switching a pull-up on
  }
}

// key that is held down right now, 0 if none
char scanKeypad() {
  char found = 0;

  for (byte c = 0; c < 4 && found == 0; c++) {
    pinMode(COL_PINS[c], OUTPUT);     // pull this column low
    delayMicroseconds(5);             // let the line settle
    for (byte r = 0; r < 4; r++) {
      if (digitalRead(ROW_PINS[r]) == LOW) {
        found = pgm_read_byte(&KEYS[r][c]);
        break;
      }
    }
    pinMode(COL_PINS[c], INPUT);      // back to high-Z
  }
  return found;
}

// debounced, reports a key once when it is pressed down
char getKeyPress() {
  static char stableKey = 0;
  static char lastRead  = 0;
  static unsigned long lastChange = 0;

  char k = scanKeypad();

  if (k != lastRead) {                // still bouncing
    lastRead = k;
    lastChange = millis();
    return 0;
  }
  if (millis() - lastChange < DEBOUNCE_MS) {
    return 0;
  }
  if (k == stableKey) {               // nothing new
    return 0;
  }
  stableKey = k;
  return k;                           // 0 here means "key released"
}

// ---------------------------------------------------------------------------
// Keypad input
// ---------------------------------------------------------------------------
void handleKeypad() {
  // drop a half-typed PIN (or a lone 'A' admin request) after a while so
  // nothing stays on the screen and a later PIN entry is not misread as an
  // admin PIN
  if ((entryLen > 0 || enteringAdmin) && millis() - lastKeyMs > ENTRY_TIMEOUT_MS) {
    clearEntry();
    enteringAdmin = false;
    displayDirty = true;
  }

  char key = getKeyPress();
  if (key == 0) {
    return;
  }
  lastKeyMs = millis();

  Serial.print(F("[KEY] "));
  Serial.println(key);

  if (key >= '0' && key <= '9') {
    if (entryLen < MAX_ENTRY_LEN) {
      entry[entryLen++] = key;
      entry[entryLen] = '\0';
      clickBeep();
    }
    displayDirty = true;
  } else if (key == '*') {
    clearEntry();
    enteringAdmin = false;
    clickBeep();
    displayDirty = true;
  } else if (key == '#') {
    submitEntry();
  } else if (key == 'A' && state == STATE_DISARMED && entryLen == 0) {
    enteringAdmin = true;
    clickBeep();
    displayDirty = true;
  } else if (key == 'B' && state == STATE_DISARMED && entryLen == 0) {
    resetRfid();
  }
  // C-D are not used
}

void clearEntry() {
  entryLen = 0;
  entry[0] = '\0';
}

// Check the typed PIN (or, while enteringAdmin, the admin PIN) and act on it
void submitEntry() {
  if (enteringAdmin) {
    bool adminOk = (entryLen > 0 && strcmp(entry, ADMIN_PIN) == 0);
    enteringAdmin = false;
    clearEntry();
    displayDirty = true;

    if (adminOk) {
      Serial.println(F("[ADMIN] PIN correct, opening menu"));
      openAdminMenu();
    } else {
      Serial.println(F("[ADMIN] wrong PIN"));
      accessDenied(F("too many wrong admin PIN entries"));
    }
    return;
  }

  bool ok = (entryLen > 0 && strcmp(entry, PIN_CODE) == 0);

  Serial.print(F("[PIN] entered: "));
  Serial.println(entry);
  clearEntry();
  displayDirty = true;

  if (ok) {
    Serial.println(F("[PIN] correct"));
    accessGranted();
  } else {
    Serial.print(F("[PIN] wrong, try "));
    Serial.println(wrongTries + 1);
    accessDenied(F("too many wrong PIN entries"));
  }
}

// ---------------------------------------------------------------------------
// RFID - a known card does exactly what the correct PIN does
// ---------------------------------------------------------------------------

// Polls the reader; on a new card, leaves its UID in mfrc522.uid and returns
// true. Shared by normal operation and the admin "add card" screen.
bool readNewCardUid() {
  if (!rfidOk || millis() - lastRfidPoll < RFID_POLL_MS) {
    return false;
  }
  lastRfidPoll = millis();

  if (!mfrc522.PICC_IsNewCardPresent() || !mfrc522.PICC_ReadCardSerial()) {
    return false;
  }

  Serial.print(F("[RFID] uid:"));
  for (byte i = 0; i < mfrc522.uid.size; i++) {
    Serial.print(' ');
    Serial.print(mfrc522.uid.uidByte[i], HEX);
  }
  Serial.println();

  // HaltA sends the card to sleep, so leaving it on the reader does not
  // retrigger - it answers again only after being taken away and back.
  mfrc522.PICC_HaltA();
  return true;
}

// RC522 clones occasionally stop answering over SPI (VersionReg then reads
// 0x00/0xFF again). Re-running the reset/init sequence brings them back
// without a full board reset. Triggered manually via keypad 'B'.
void resetRfid() {
  Serial.println(F("[RFID] manual reset"));
  mfrc522.PCD_Reset();
  mfrc522.PCD_Init();

  byte ver = mfrc522.PCD_ReadRegister(MFRC522::VersionReg);
  rfidOk = (ver != 0x00 && ver != 0xFF);
  Serial.print(F("[RFID] version 0x"));
  Serial.println(ver, HEX);

  if (rfidOk) {
    startSound(SOUND_OK);
  } else {
    Serial.println(F("[RFID] still not answering"));
    startSound(SOUND_ERROR);
  }
}

void handleRfid() {
  if (!readNewCardUid()) {
    return;
  }

  if (uidAllowed()) {
    Serial.println(F("[RFID] known card"));
    accessGranted();
  } else {
    Serial.println(F("[RFID] unknown card"));
    accessDenied(F("too many unknown cards"));
  }
}

// is the UID just read one of the cards stored in EEPROM?
bool uidAllowed() {
  if (mfrc522.uid.size != UID_LEN) {
    return false;                        // wrong card family, cannot match
  }
  return findStoredUid(mfrc522.uid.uidByte) != -1;
}

// index of the given UID in storedUids, or -1 if it is not stored
int findStoredUid(const byte *uid) {
  for (byte c = 0; c < storedUidCount; c++) {
    bool match = true;
    for (byte i = 0; i < UID_LEN; i++) {
      if (uid[i] != storedUids[c][i]) {
        match = false;
        break;
      }
    }
    if (match) {
      return c;
    }
  }
  return -1;
}

// ---------------------------------------------------------------------------
// UID storage (EEPROM) - see "Settings" section above for the layout
// ---------------------------------------------------------------------------
void loadUidsFromEeprom() {
  if (EEPROM.read(EEPROM_MAGIC_ADDR) != EEPROM_MAGIC) {
    // blank / fresh chip - seed EEPROM with the factory default list
    storedUidCount = min(DEFAULT_UID_COUNT, MAX_STORED_UIDS);
    for (byte c = 0; c < storedUidCount; c++) {
      for (byte i = 0; i < UID_LEN; i++) {
        storedUids[c][i] = pgm_read_byte(&DEFAULT_UIDS[c][i]);
      }
    }
    saveUidsToEeprom();
    Serial.println(F("[EEPROM] blank chip, wrote factory default UIDs"));
    return;
  }

  storedUidCount = EEPROM.read(EEPROM_COUNT_ADDR);
  if (storedUidCount > MAX_STORED_UIDS) {
    Serial.println(F("[EEPROM] bad stored count, resetting to 0"));
    storedUidCount = 0;
    saveUidsToEeprom();
    return;
  }

  for (byte c = 0; c < storedUidCount; c++) {
    for (byte i = 0; i < UID_LEN; i++) {
      storedUids[c][i] = EEPROM.read(EEPROM_DATA_ADDR + c * UID_LEN + i);
    }
  }
}

// writes the magic byte, the count and every stored UID back to EEPROM.
// EEPROM.update() only actually writes a byte when its value changed, so
// repeated calls do not wear the EEPROM out.
void saveUidsToEeprom() {
  EEPROM.update(EEPROM_MAGIC_ADDR, EEPROM_MAGIC);
  EEPROM.update(EEPROM_COUNT_ADDR, storedUidCount);
  for (byte c = 0; c < storedUidCount; c++) {
    for (byte i = 0; i < UID_LEN; i++) {
      EEPROM.update(EEPROM_DATA_ADDR + c * UID_LEN + i, storedUids[c][i]);
    }
  }
}

// adds a UID if there is room and it is not already stored
bool addUid(const byte *uid) {
  if (storedUidCount >= MAX_STORED_UIDS) {
    return false;
  }
  for (byte i = 0; i < UID_LEN; i++) {
    storedUids[storedUidCount][i] = uid[i];
  }
  storedUidCount++;
  saveUidsToEeprom();
  return true;
}

// removes the UID at the given index, shifting the rest down
void deleteUidAt(byte index) {
  if (index >= storedUidCount) {
    return;
  }
  for (byte c = index; c < storedUidCount - 1; c++) {
    for (byte i = 0; i < UID_LEN; i++) {
      storedUids[c][i] = storedUids[c + 1][i];
    }
  }
  storedUidCount--;
  saveUidsToEeprom();
}

// ---------------------------------------------------------------------------
// Access decision - shared by keypad and RFID
// ---------------------------------------------------------------------------
void accessGranted() {
  wrongTries = 0;
  displayDirty = true;

  switch (state) {
    case STATE_ALARM:
    case STATE_ARMED:
    case STATE_EXIT_DELAY:
      setState(STATE_DISARMED);
      Serial.println(F("[STATE] disarmed"));
      break;
    case STATE_DISARMED:
      setState(STATE_EXIT_DELAY);
      Serial.println(F("[STATE] arming - exit delay running"));
      break;
  }
  startSound(SOUND_OK);
}

void accessDenied(const __FlashStringHelper *reason) {
  wrongTries++;
  displayDirty = true;

  if (wrongTries >= MAX_WRONG_TRIES) {
    wrongTries = 0;
    triggerAlarm(reason);
  } else {
    startSound(SOUND_ERROR);
  }
}

// ---------------------------------------------------------------------------
// Admin menu - manage RFID cards from the keypad/OLED, see CLAUDE.md
// ---------------------------------------------------------------------------
void openAdminMenu() {
  adminScreen = ADMIN_MENU;
  adminListIndex = 0;
  adminMsg = nullptr;
  lastAdminKeyMs = millis();
  setState(STATE_ADMIN);
  startSound(SOUND_OK);
}

void showAdminMsg(const __FlashStringHelper *msg) {
  adminMsg = msg;
  adminMsgUntil = millis() + ADMIN_MSG_MS;
  displayDirty = true;
}

void handleAdminKeypad() {
  // leave the menu on its own if nobody touches it for a while
  if (millis() - lastAdminKeyMs > ADMIN_IDLE_TIMEOUT_MS) {
    Serial.println(F("[ADMIN] idle timeout, closing menu"));
    setState(STATE_DISARMED);
    return;
  }

  char key = getKeyPress();
  if (key == 0) {
    return;
  }
  lastAdminKeyMs = millis();

  Serial.print(F("[ADMIN KEY] "));
  Serial.println(key);

  switch (adminScreen) {
    case ADMIN_MENU:
      if (key == '1') {
        adminScreen = ADMIN_ADD_WAIT;
        clickBeep();
        displayDirty = true;
      } else if (key == '2') {
        adminScreen = ADMIN_LIST;
        adminListIndex = 0;
        clickBeep();
        displayDirty = true;
      } else if (key == '*') {
        Serial.println(F("[ADMIN] menu closed"));
        setState(STATE_DISARMED);
      }
      break;

    case ADMIN_ADD_WAIT:
      if (key == '*') {
        adminScreen = ADMIN_MENU;
        clickBeep();
        displayDirty = true;
      }
      break;

    case ADMIN_LIST:
      if (key == '*') {
        adminScreen = ADMIN_MENU;
        clickBeep();
        displayDirty = true;
      } else if (key == '#') {
        if (storedUidCount > 0) {
          adminListIndex = (adminListIndex + 1) % storedUidCount;
        }
        clickBeep();
        displayDirty = true;
      } else if (key == 'D' && storedUidCount > 0) {
        deleteUidAt(adminListIndex);
        if (adminListIndex >= storedUidCount && storedUidCount > 0) {
          adminListIndex = storedUidCount - 1;
        }
        Serial.println(F("[ADMIN] card deleted"));
        showAdminMsg(F("Deleted"));
      }
      break;
  }
}
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

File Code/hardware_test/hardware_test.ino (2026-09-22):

/*
 * hardware_test.ino
 * Bring-up test for the Arduino Security/Access circuit (see MDs/aufbau.md).
 *
 * Purpose: check that every attached component responds. This is NOT the
 * final firmware - it only exercises the hardware and prints results to the
 * Serial Monitor (9600 baud) and to the OLED.
 *
 * Wiring used by this test (from aufbau.md):
 *   4x4 Keypad rows R1..R4 -> D9, D8, D7, D6
 *   4x4 Keypad cols C1..C4 -> D5, D4, D3, D2
 *   Passive buzzer signal  -> D10
 *   Motion sensor OUT      -> A2
 *   OLED I2C               -> SDA / SCL  (see note below)
 *   All VCC -> 5V, all GND -> GND
 *
 * ---------------------------------------------------------------------------
 * ASSUMPTIONS (not specified in aufbau.md - change if your parts differ):
 *   1. OLED is an SH1106 128x64, I2C address 0x3C.
 *   2. Keypad key layout is the common 4x4 matrix:
 *        1 2 3 A / 4 5 6 B / 7 8 9 C / * 0 # D
 *   3. Motion sensor OUT is active HIGH when motion is detected.
 *
 * NOTE ON I2C PINS:
 *   aufbau.md records OLED SDA -> A5 and SCL -> A4. On the Arduino Uno the
 *   hardware I2C bus is fixed: SDA = A4, SCL = A5. The Wire library (used by
 *   the OLED library) can only use those fixed pins. If the OLED test fails,
 *   the SDA/SCL wires are almost certainly swapped - move SDA to A4 and
 *   SCL to A5.
 *
 * Required libraries (Library Manager):
 *   - Keypad            by Mark Stanley / Alexander Brevig
 *   - Adafruit SH110X   (SH1106 / SH1107 controllers)
 *   - Adafruit GFX
 * ---------------------------------------------------------------------------
 */

#include <Wire.h>
#include <Keypad.h>
#include <Adafruit_GFX.h>
#include <Adafruit_SH110X.h>

// ----- Pin configuration --------------------------------------------------
const byte ROW_PINS[4] = {9, 8, 7, 6};   // R1, R2, R3, R4
const byte COL_PINS[4] = {5, 4, 3, 2};   // C1, C2, C3, C4

const byte BUZZER_PIN = 10;
const byte MOTION_PIN = A2;

// ----- OLED -------------------------------------------------------------
#define SCREEN_WIDTH 128
#define SCREEN_HEIGHT 64
#define OLED_RESET    -1
#define OLED_ADDRESS  0x3C
Adafruit_SH1106G display(SCREEN_WIDTH, SCREEN_HEIGHT, &Wire, OLED_RESET);

// ----- Keypad ---------------------------------------------------------
const char KEYS[4][4] = {
  {'1', '2', '3', 'A'},
  {'4', '5', '6', 'B'},
  {'7', '8', '9', 'C'},
  {'*', '0', '#', 'D'}
};
Keypad keypad = Keypad(makeKeymap(KEYS),
                       (byte *)ROW_PINS, (byte *)COL_PINS, 4, 4);

// ----- Test state -------------------------------------------------------
bool oledOk = false;
int  keysSeen = 0;
char lastKey = ' ';

void setup() {
  Serial.begin(9600);
  while (!Serial) { ; }  // wait for Serial Monitor on boards that need it

  Serial.println();
  Serial.println(F("=== Hardware bring-up test ==="));

  pinMode(MOTION_PIN, INPUT);
  pinMode(BUZZER_PIN, OUTPUT);
  digitalWrite(BUZZER_PIN, LOW);

  testOled();
  testBuzzer();

  Serial.println(F("Setup done. Now testing keypad + motion sensor."));
  Serial.println(F("Press every key once. Wave a hand in front of the sensor."));
  showStatus("Press keys /", "wave at sensor");
}

void loop() {
  checkKeypad();
  checkMotion();
}

// ---------------------------------------------------------------------------
// OLED: initialise and draw a test pattern
// ---------------------------------------------------------------------------
void testOled() {
  Serial.print(F("[OLED] init at 0x"));
  Serial.print(OLED_ADDRESS, HEX);
  Serial.print(F(" ... "));

  if (display.begin(OLED_ADDRESS, true)) {
    oledOk = true;
    Serial.println(F("OK"));

    display.clearDisplay();
    display.setTextSize(1);
    display.setTextColor(SH110X_WHITE);
    display.setCursor(0, 0);
    display.println(F("OLED OK"));
    display.println(F("Hardware test"));
    display.drawRect(0, 20, SCREEN_WIDTH, 20, SH110X_WHITE);
    display.fillRect(2, 22, SCREEN_WIDTH - 4, 16, SH110X_WHITE);
    display.display();
    delay(1500);
  } else {
    oledOk = false;
    Serial.println(F("FAILED"));
    Serial.println(F("       -> check power and SDA=A4 / SCL=A5 (Uno fixed pins),"));
    Serial.println(F("          try address 0x3D, check the OLED controller type."));
  }
}

// ---------------------------------------------------------------------------
// Buzzer: short beep sequence, must be audible
// ---------------------------------------------------------------------------
void testBuzzer() {
  Serial.print(F("[BUZZER] beep test on D"));
  Serial.print(BUZZER_PIN);
  Serial.println(F(" ... listen for 3 tones"));

  const int freqs[3] = {1000, 1500, 2000};
  for (int i = 0; i < 3; i++) {
    tone(BUZZER_PIN, freqs[i], 150);
    delay(250);
  }
  noTone(BUZZER_PIN);
  Serial.println(F("[BUZZER] done (confirm you heard it)"));
}

// ---------------------------------------------------------------------------
// Keypad: report each key press
// ---------------------------------------------------------------------------
void checkKeypad() {
  char key = keypad.getKey();
  if (key == NO_KEY) {
    return;
  }

  keysSeen++;
  lastKey = key;

  Serial.print(F("[KEYPAD] key = '"));
  Serial.print(key);
  Serial.print(F("'  (total presses: "));
  Serial.print(keysSeen);
  Serial.println(F(")"));

  // short feedback beep so keypad + buzzer are tested together
  tone(BUZZER_PIN, 1800, 40);

  char line1[17];
  char line2[17];
  snprintf(line1, sizeof(line1), "Key: %c", key);
  snprintf(line2, sizeof(line2), "Count: %d", keysSeen);
  showStatus(line1, line2);
}

// ---------------------------------------------------------------------------
// Motion sensor: report state changes only
// ---------------------------------------------------------------------------
void checkMotion() {
  static int lastState = -1;
  int state = digitalRead(MOTION_PIN);

  if (state != lastState) {
    lastState = state;
    Serial.print(F("[MOTION] "));
    Serial.println(state == HIGH ? F("motion DETECTED") : F("clear"));

    if (oledOk) {
      display.fillRect(0, 52, SCREEN_WIDTH, 12, SH110X_BLACK);
      display.setCursor(0, 54);
      display.print(state == HIGH ? F("MOTION!") : F("no motion"));
      display.display();
    }

    if (state == HIGH) {
      tone(BUZZER_PIN, 2500, 120);
    }
  }
}

// ---------------------------------------------------------------------------
// Helper: two short lines on the OLED (ignored if OLED failed)
// ---------------------------------------------------------------------------
void showStatus(const char *line1, const char *line2) {
  if (!oledOk) {
    return;
  }
  display.clearDisplay();
  display.setTextSize(1);
  display.setTextColor(SH110X_WHITE);
  display.setCursor(0, 0);
  display.println(line1);
  display.println(line2);
  display.display();
}

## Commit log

2026-09-22 Iniital commit
    [Teile.xlsx]
2026-09-23 Add animated README graphics, 3D viewer and new README
    - docs/banner.svg, how-it-works.svg, wiring.svg: animated SVGs
    - docs/viewer: three.js 3D model of the build with the firmware
    logic of alarm_system.ino ported to JavaScript (demo PINs)
    - GitHub Pages workflow for the viewer
    - README rewritten, CLAUDE.md and development log updated
2026-09-23 3D Case Prototype
    [control_back.stl, control_front.stl, gehaeuse.scad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]
